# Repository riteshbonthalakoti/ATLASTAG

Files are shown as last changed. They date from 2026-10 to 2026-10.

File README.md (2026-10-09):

# AtlasTag

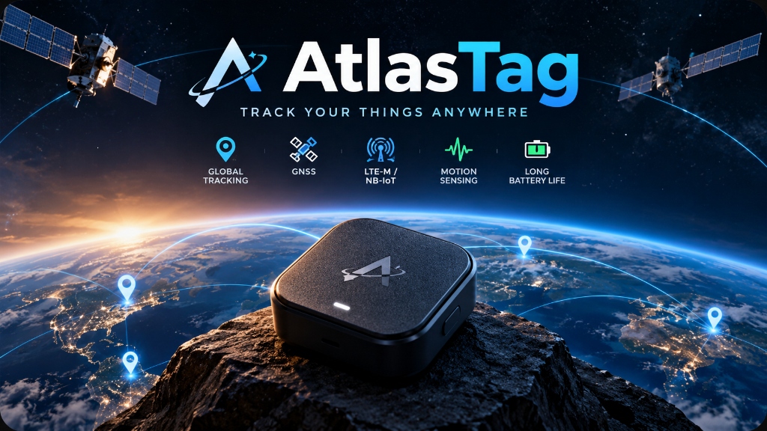
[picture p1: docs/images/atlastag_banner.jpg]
AtlasTag Banner


> **AtlasTag** is an ultra-compact, long-battery-life hardware asset-tracking platform combining GNSS satellite positioning, cellular IoT connectivity (LTE-M / NB-IoT), motion-triggered intelligence, and local fail-safe telemetry storage. Developed for **Hack Club Half Life**.

---

## Concept & Vision Reel

> [!NOTE]
> **Idea & Concept Showcase:** This video is an **idea reel / conceptual mockup** visualizing the intended asset-tracking experience, compact form-factor goals, and operational scenario for AtlasTag. It illustrates the project goals rather than physical bench-tested hardware (hardware design and subsystem validation are currently underway in Week 1).

https://github.com/user-attachments/assets/558ffe17-422e-43a5-9f9e-540db29d0795

---

## The Problem & The AtlasTag Approach

Most popular asset trackers (such as Apple AirTags or Tile) rely exclusively on crowd-sourced Bluetooth networks. When an asset leaves urban density or moves along transit highways, rural routes, or industrial yards without nearby smartphones, **tracking is lost**.

AtlasTag is engineered to operate **fully autonomously**:
- **Direct Satellite Positioning:** Acquires real-world geographic coordinates via multi-constellation GNSS (GPS, GLONASS, Galileo, BeiDou) without relying on external devices.
- **Direct Cellular Telemetry:** Transmits location packets directly to cloud servers over power-efficient LTE-M or NB-IoT networks.
- **Fail-Safe Offline Storage:** When traversing cellular dead zones or shielded containers, telemetry records are queued in local SPI NOR Flash memory and uploaded automatically once coverage is restored.
- **Ultra-Low Power Motion Gating:** Stays in deep micro-ampere sleep when stationary, waking up instantaneously via accelerometer interrupts when motion or tampering is detected.

---

## Visual Architecture & Data Flow

```mermaid
flowchart LR
    %% Main Pipeline
    Motion["🚶 Motion Sensor<br/><b>(Detects Movement)</b>"]
    -->|"1. Hardware Interrupt"| Brain["🧠 Host MCU / Controller<br/><b>(System Logic)</b>"]

    GPS["🛰️ GNSS Satellites<br/><b>(Latitude / Longitude)</b>"]
    -->|"2. Position Fix"| Brain

    Brain
    -->|"3. Formats Packet"| Modem["📶 Cellular Modem<br/><b>(LTE-M / NB-IoT)</b>"]

    Modem
    -->|"4. Cloud Uplink"| CloudApp["📱 Web / Mobile App<br/><b>(Live Map & Alerts)</b>"]

    %% Backup Storage
    Modem -.->|"No Signal (Offline)"| Storage["💾 SPI NOR Flash<br/><b>(Queues Telemetry)</b>"]
    Storage -.->|"Burst Upload on Reconnect"| Modem

    %% Power
    Power["🔋 Li-Po Battery & Charger<br/><b>(Power Management)</b>"]
    ==>|"Regulated 3.3V & VBAT Burst"| Brain

    %% Styling
    style Motion fill:#E8F5E9,stroke:#2E7D32,stroke-width:2px,color:#1B5E20
    style GPS fill:#E1F5FE,stroke:#0288D1,stroke-width:2px,color:#01579b
    style Brain fill:#EDE7F6,stroke:#512DA8,stroke-width:2px,color:#311B92
    style Modem fill:#FFF3E0,stroke:#E65100,stroke-width:2px,color:#BF360C
    style CloudApp fill:#FCE4EC,stroke:#C2185B,stroke-width:2px,color:#880E4F
    style Storage fill:#FFFDE7,stroke:#FBC02D,stroke-width:2px,color:#F57F17
    style Power fill:#ECEFF1,stroke:#455A64,stroke-width:2px,color:#263238
```

### The 5-Step Operating Cycle

1. **Deep Sleep Preservation:** Between tracking events, the system enters deep sleep, turning off RF radios to maximize battery longevity.
2. **Motion-Triggered Wakeup:** When vibration or acceleration exceeds the programmed threshold, the low-power accelerometer asserts a hardware interrupt pin to wake the host controller.
3. **Satellite GNSS Fix:** The GNSS receiver powers on, locks ephemeris data, and acquires high-accuracy geographic coordinates.
4. **Cellular Uplink:** The cellular engine establishes an LTE-M / NB-IoT network bearer and pushes the telemetry packet to the endpoint.
5. **Store-and-Forward Safety Net:** If no cellular tower acknowledges transmission, the packet is written to the on-board Winbond SPI Flash queue and forwarded during the next successful network attachment.

---

## Current Status: Week 1 Modular Baseboard

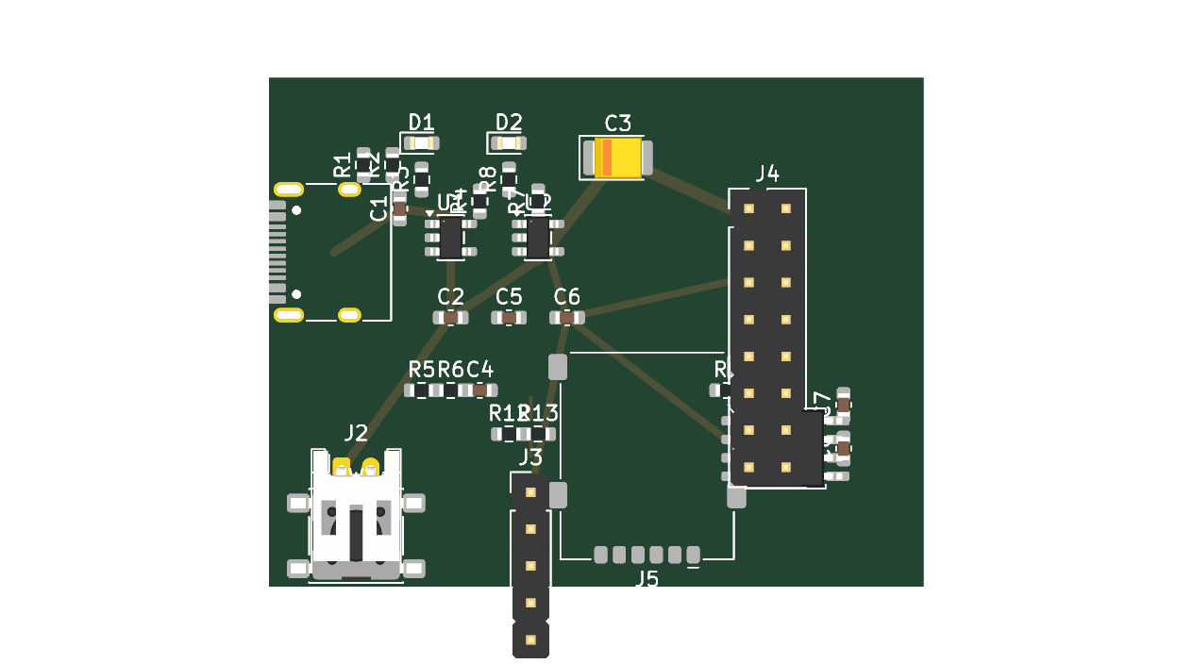
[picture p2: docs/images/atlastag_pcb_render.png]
AtlasTag Baseboard 3D Render

*AtlasTag Week 1 Modular Prototype Baseboard (45 × 35 mm, 4-Layer Controlled-Impedance Stackup).*

### Current Engineering State:
- **Schematic Capture Complete:** Authoritative baseboard schematic captured in KiCad 10.0.6 (`hardware/kicad/atlastag.kicad_sch`), passing electrical rules check (ERC) with zero critical errors.
- **Modular Mezzanine Architecture:** Implements a standardized 16-pin interface (VBAT, 3.3V, GND, UART, control GPIOs, SIM interface), keeping the Cellular/GNSS modem selection **open** and avoiding unverified fine-pitch BGA/LGA soldering risks.
- **Power Path Design:**
  - **USB-C Interface:** Mid-mount receptacle with dual 5.1 kΩ CC pull-downs for standard 5V supply negotiation.
  - **Battery Charger:** Microchip MCP73831 linear Li-Po charger with $R_{PROG} = 4.7\text{ k}\Omega$ setting a safe 212 mA charging current limit.
  - **System LDO:** Diodes Inc AP2112K-3.3 (600 mA, ultra-low dropout) supplying clean 3.3V power.
  - **Burst Current Reservoir:** Dedicated 100 µF 10V low-ESR ceramic capacitor on the VBAT rail to buffer RF transmission bursts.
- **Telemetry Queue Memory:** Winbond W25Q32JVSSIQ (32 Mb / 4 MB) SPI NOR Flash in an iron-solderable SOIC-8 package.
- **Motion Sensor Interface:** 5-pin 2.54 mm breakout header (3V3, GND, SCL, SDA, INT) for modular MEMS accelerometer integration.
- **Layout & Routing Status:** Preliminary 4-layer layout drafted (45 × 35 mm). Full internal plane copper pours, signal routing, and interactive KiCad DRC remain pending physical board completion. Fabrication outputs are currently marked **STRICTLY NOT FOR FABRICATION**.

---

## Hardware Architecture: Modular Baseboard + Mezzanine

To reconcile strict hand-assembly constraints (soldering iron only) with high-density cellular modules, AtlasTag separates the design into two distinct layers:

| Layer | Function | Primary Components | Assembly Method |
| :--- | :--- | :--- | :--- |
| **Baseboard (45 × 35 mm)** | Power management, charging, battery monitoring, offline flash, SIM interface, sensor header | MCP73831, AP2112K-3.3, Winbond W25Q32, Nano-SIM socket, USB-C | 100% Iron-Solderable (0603 passives, SOT-23-5, SOIC-8, through-hole headers) |
| **Carrier / Mezzanine** | Cellular connectivity (LTE-M/NB-IoT), GNSS receiver, RF front-end | Nordic nRF9151, Quectel BG95-M3, or SIMCom SIM7080G carrier | Pre-assembled SMT carrier or breakout connecting via 16-pin 2.54 mm header |

---

## Cellular / GNSS Platform Trade Study (Status: OPEN)

The primary modem platform decision remains **deliberately open** to ensure rigorous verification of network compatibility and hand-assembly feasibility:

| Candidate | Form Factor | Connectivity | Internal MCU | Assembly Assessment |
| :--- | :--- | :--- | :--- | :--- |
| **Nordic nRF9151** | Compact SiP (11×12 mm) | LTE-M / NB-IoT / GNSS | ARM Cortex-M33 (64 MHz, 1 MB Flash) | High density; requires pre-assembled mezzanine carrier for iron assembly. |
| **Quectel BG95-M3** | SMT Module (23.6×19.9 mm) | LTE-M / NB-IoT / EGPRS / GNSS | Requires external host MCU | Standard cellular module; requires carrier breakout or stencil reflow. |
| **SIMCom SIM7080G** | SMT Module (17.6×15.7 mm) | LTE-M / NB-IoT / GNSS | Requires external host MCU | Readily available development breakouts; low entry cost. |

> **Network Note:** Reliance Jio NB-IoT SIM provisioning and local band coverage in India remain **unverified** pending active carrier SIM acquisition and bench validation.

---

## Bill of Materials & Budget Compliance

AtlasTag is developed within the **Hack Club Half Life Tier 3 budget limit of $100.00 USD** (~₹9,670 INR at verified rate ₹96.70/USD).

| Subsystem | Cost (USD) | Cost (INR @ ₹96.70) | Notes |
| :--- | :--- | :--- | :--- |
| **Physical Baseboard Parts** | **$11.70** | **₹1,131.41** | All baseboard SMT components, charger, regulator, flash, SIM socket, headers |
| **Core System Projection** | **$44.25** | **₹4,278.98** | Baseboard + candidate cellular/GNSS engine + Li-Po cell + antennas |
| **Budget Headroom** | **+$55.75** | **+₹5,391.02** | Remaining contingency under the $100.00 USD Tier 3 grant limit |

Authoritative component details, manufacturer part numbers (MPNs), and distributor URLs are tracked in [`bom/BOM.md`](bom/BOM.md) and [`bom.csv`](bom.csv).

---

## Repository Structure

```text
ATLASTAG/
├── bom/                      # Authoritative detailed Bill of Materials (BOM.md, bom.csv)
├── docs/
│   ├── architecture/         # System architecture & hardware block diagrams
│   ├── decisions/            # Formal engineering trade study logs (DECISION_LOG.md)
│   ├── requirements/         # System requirements & project boundary gates
│   └── research/             # Component research, datasheets & network investigations
├── firmware/
│   └── src/                  # Architectural state machine stubs & driver development
├── hardware/
│   ├── gerbers/              # Fabrication files (Marked NOT FOR FABRICATION during draft)
│   └── kicad/                # KiCad 10 schematic (*.kicad_sch), PCB (*.kicad_pcb), netlist
└── README.md                 # Primary project documentation
```

---

## Development Workflow & Rules

- **Branch Model:** All active engineering occurs on branch `dev`. Stable milestones are promoted to `main` strictly through reviewed pull requests.
- **Truthful Engineering Integrity:** No subsystem is labeled as verified without bench testing, code implementation, and reproducible CLI reports.
- **Tooling:** KiCad 10.0.6 CLI automation, Git Conventional Commits (`feat:`, `fix:`, `docs:`, `chore:`).

---

## Hack Club Half Life

AtlasTag is an independent open-hardware development project created for the **Hack Club Half Life** hardware initiative.

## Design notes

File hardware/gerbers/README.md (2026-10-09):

# AtlasTag Fabrication Outputs (Gerbers & Drill)

> **STATUS: PRELIMINARY CHECKPOINT EXPORT — STRICTLY NOT FOR FABRICATION**  
> **Date:** October 9, 2026  
> **Tool:** KiCad 10.0.6 (`kicad-cli`)

---

## Critical Notice

These Gerber and Excellon drill files represent the Week 1 prototype board outline (45 × 35 mm on `Edge.Cuts`) and preliminary footprint placements for toolchain validation.

### Engineering Fabrication Gate:
- **Routing Status:** Incomplete. Full signal routing (SPI, UART, SIM) and internal ground/power plane polygon pours (`In1.GND`, `In2.PWR`) are not completed.
- **DRC Verification:** **NOT VERIFIED.** KiCad Design Rules Check (DRC) requires interactive GUI verification and has not been executed.
- **Ordering Advisory:** **DO NOT ORDER, SUBMIT, OR QUOTE THESE GERBERS FOR PCB FABRICATION.** Production manufacturing outputs will only be generated after schematic signoff, complete manual PCB routing, ground pour stitching, and a clean KiCad GUI DRC report.

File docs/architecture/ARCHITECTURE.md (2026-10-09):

# System Architecture: AtlasTag

*Status: DRAFT (Under Research Phase)*

---

## Visual Architecture & Flow

A simple, single-view diagram showing how AtlasTag tracks assets and delivers location updates to the user.

```mermaid
flowchart LR
    %% Main Pipeline
    Motion["🚶 Motion Sensor<br/><b>(Detects Movement)</b>"]
    -->|"1. Wakes up"| Brain["🧠 Microcontroller<br/><b>(Main Brain)</b>"]

    GPS["🛰️ GPS Satellites<br/><b>(Finds Coordinates)</b>"]
    -->|"2. Sends location"| Brain

    Brain
    -->|"3. Formats message"| Modem["📶 Cellular Modem<br/><b>(4G / LTE-M)</b>"]

    Modem
    -->|"4. Uploads over internet"| CloudApp["📱 User's Phone<br/><b>(Live Map & Alerts)</b>"]

    %% Backup Storage
    Modem -.->|"No signal? (Backup)"| Storage["💾 Flash Memory<br/><b>(Saves offline data)</b>"]
    Storage -.->|"Upload when back online"| Modem

    %% Power
    Power["🔋 Battery & Charger<br/><b>(Powers everything)</b>"]
    ==>|"Continuous Power"| Brain

    %% High-contrast, clean styling
    style Motion fill:#E8F5E9,stroke:#2E7D32,stroke-width:2px,color:#1B5E20
    style GPS fill:#E1F5FE,stroke:#0288D1,stroke-width:2px,color:#01579b
    style Brain fill:#EDE7F6,stroke:#512DA8,stroke-width:2px,color:#311B92
    style Modem fill:#FFF3E0,stroke:#E65100,stroke-width:2px,color:#BF360C
    style CloudApp fill:#FCE4EC,stroke:#C2185B,stroke-width:2px,color:#880E4F
    style Storage fill:#FFFDE7,stroke:#FBC02D,stroke-width:2px,color:#F57F17
    style Power fill:#ECEFF1,stroke:#455A64,stroke-width:2px,color:#263238
```

---

## How It Works (The 5-Step Flow)

1. **Sleeps to Save Battery:** Most of the time, the device stays asleep to last months on a small battery.
2. **Wakes Up on Movement:** When someone moves the tracked object, the motion sensor detects it and immediately wakes the brain (microcontroller).
3. **Finds Its Location:** The GPS receiver powers on, connects to satellites, and locks the exact coordinates (latitude and longitude). If indoors, it uses nearby cellular towers as a fallback.
4. **Sends Location to Your Phone:** The cellular modem wakes up and sends the location packet over 4G LTE-M to the cloud, updating the mobile app in real time.
5. **Offline Safety Net:** If the device is out of cellular coverage (e.g., in a basement or shipping container), it saves the location history to internal flash memory and uploads everything automatically once signal returns.

---

## Power System
- **Battery:** 3.7V rechargeable Li-Po battery (~400–800 mAh).
- **Charging:** Standard USB-C charging with built-in battery management (PMIC).
- **Efficiency:** Turns off GPS and cellular antennas between updates to achieve under 10 µA standby current.

---

## Location Strategy
- **Outdoor:** High-accuracy GPS / GNSS (< 5 meters).
- **Indoor Fallback:** Cellular tower triangulation if satellite signals are blocked.

---

## Sleep & Wake Triggers
- **Motion Trigger:** Wakes immediately when movement or vibration is detected.
- **Heartbeat Timer:** Wakes periodically (e.g., once every 12 hours) even if stationary to report battery status and check in.
- **Charger Trigger:** Wakes automatically when plugged into USB-C.

---

## Hardware Component Summary

| Role | Component Candidate | Purpose | Iron-Only Assembly Feasibility |
| :--- | :--- | :--- | :--- |
| **Main Brain & Modem** | Nordic nRF9151 / Quectel BG95-M3 / SIM7080G | Runs device logic, reads GPS, connects to NB-IoT/LTE-M | PENDING (Via Mezzanine Header) |
| **Battery Charger** | Microchip MCP73831 (SOT-23-5) | Safe CC/CV single-cell Li-Po charging from USB-C | 100% Solderable (Gull-wing leads) |
| **System Voltage Regulator** | Diodes Inc AP2112K-3.3 (SOT-23-5) / Low-IQ LDO | Regulated 3.3V rail for host, flash, and sensors | 100% Solderable (Gull-wing leads) |
| **Motion Sensor** | ST LIS2DW12 / Pre-soldered MEMS Breakout | Ultra-low power accelerometer for motion wake | Header Breakout (Bare LGA unresolved) |
| **Offline Memory** | Winbond W25Q32JVSSIQ (SOIC-8) | Stores unsent location records when off-grid | 100% Solderable (1.27 mm gull-wing) |
| **SIM Card Socket** | Molex 104224-0820 Nano-SIM | Provides cellular network carrier interface | Solderable perimeter SMT pads |
| **Modem Interface Header** | Dual-Row 2.54mm Mezzanine Header | Decouples modem footprint from baseboard | 100% Solderable Through-Hole |

---

## Modular Prototype Architecture (Baseboard + Mezzanine)

To decouple unverified fine-pitch modem footprints and enable iron-only hand assembly during Week 1, AtlasTag implements a modular architecture:
- **Baseboard (45 × 35 mm):** Contains the 100% iron-solderable power path (USB-C, MCP73831 charger, 3.3V LDO), battery monitor, Winbond SOIC-8 flash, Nano-SIM socket, status LEDs, and sensor breakout header.
- **Modem Mezzanine Header:** Standardized 12-pin interface providing VBAT (burst power), 3.3V, GND, UART (TX/RX/RTS/CTS), control GPIOs (PWRKEY, RESET, STATUS), and SIM lines.
- **Trade-Offs:**
  - *Size:* Adds ~3–5 mm in vertical Z-stack height compared to a monolithic SiP, while remaining compact (45×35 mm).
  - *RF:* Eliminates high-risk RF microstrip routing on the baseboard; antenna matching remains on the modem module/carrier or connects via U.FL.
  - *Power:* High-current burst capability maintained by dual parallel VBAT and GND pins.

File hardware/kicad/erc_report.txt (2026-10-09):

ERC report (2026-10-09T16:58:27, Encoding UTF8)
Report includes: Errors, Warnings, Exclusions

***** Sheet /

 ** ERC messages: 0  Errors 0  Warnings 0

 ** Ignored checks:
    - Global label only appears once in the schematic
    - Four connection points are joined together
    - SPICE model issue
    - Assigned footprint doesn't match footprint filters

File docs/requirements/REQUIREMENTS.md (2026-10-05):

# System Requirements: AtlasTag

## Core Requirements
- **Functionality**: Global asset tracking (GNSS + Cellular).
- **Form Factor**: Slim and portable. [PENDING: Final dimensional constraints based on research]
- **Power**: Battery-powered (Li-Po), low-power operation with sleep/wake cycles.
- **Connectivity**: LTE-M / NB-IoT.

## Features (Minimum Viable Product)
- GNSS positioning
- Remote location telemetry transmission
- Motion detection (wake-on-motion)
- Battery voltage/status monitoring
- Local telemetry storage (when cellular connection drops)

## Future Expandability Options
- BLE
- Wi-Fi positioning
- UWB
- Geofencing
- Intelligent movement detection

## Constraints
- Must be genuinely manufacturable as a physical product (not just dev boards wired together).
- Realistically achievable layout and assembly.

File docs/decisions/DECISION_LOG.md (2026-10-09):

# Hardware Decision Log

## Decisions

| Date | Topic | Options Considered | Decision | Justification | Status |
|---|---|---|---|---|---|
| 2026-10-09 | Cellular/GNSS Platform | nRF9151-LACA-R, BG95-M3, SIM7080G | [PENDING] | Sourced trade study completed. With 'soldering iron only', nRF9151 (LGA-114) is impossible unless low-cost PTC hot plate (~₹450 INR) or local repair shop rework is approved. SIM7080G LCC is hand-solderable (via bottom via for center pad), but requires discrete MCU, level shifter, and external GNSS LNA. BG95-M3 has 3.3V brownout risk. Indian deployment requires NB-IoT (B3/B5/B8). Decision kept OPEN pending tooling selection and SIM/carrier verification. | OPEN |
| YYYY-MM-DD | Accelerometer | LIS2DW12, ADXL362 | LIS2DW12 (Tentative) | Excellent power profile and built-in wake features. | OPEN |
| YYYY-MM-DD | Power Management | PMIC vs Discrete | PMIC | Space constraint and ultra-low IQ requirement for PSM. | OPEN |
| YYYY-MM-DD | Storage | SPI NOR vs microSD | SPI NOR | Lower power, smaller footprint. | OPEN |
| YYYY-MM-DD | SIM Configuration | Physical (4FF) vs eSIM (MFF2) | [PENDING] | Physical is easier for testing, eSIM saves critical space. | OPEN |
| YYYY-MM-DD | Antenna Strategy | Chip/Virtual vs Ceramic Patch | [PENDING] | Space vs GNSS performance tradeoff. | OPEN |
| YYYY-MM-DD | Charging Strategy | USB-C vs Pogo pins | [PENDING] | USB-C is universal but takes space and needs sealing. | OPEN |

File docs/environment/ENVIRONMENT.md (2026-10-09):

# AtlasTag Development Environment

## Operating System
- **OS**: Microsoft Windows 11 Pro 10.0.26200

## Core Tools
- **Git**: git version 2.55.0.windows.3
- **GitHub CLI**: gh version 2.97.0
  - Authenticated as `riteshbonthalakoti` (Active)
- **Python**: Python 3.12.10
- **Node.js**: v24.19.0

## CAD / Hardware Tooling
- **KiCad Version**: 10.0.6 (Installed via winget for current user)
- **KiCad CLI Executable**: `C:\Users\bonth\AppData\Local\Programs\KiCad\10.0\bin\kicad-cli.exe`
- **KiCad GUI Executable**: `C:\Users\bonth\AppData\Local\Programs\KiCad\10.0\bin\kicad.exe`
- **KiCad Python Executable**: `C:\Users\bonth\AppData\Local\Programs\KiCad\10.0\bin\python.exe` (includes `pcbnew` 10.0.6)
- **Standard Symbol Libraries**: `C:\Users\bonth\AppData\Local\Programs\KiCad\10.0\share\kicad\symbols` (Verified present)
- **Standard Footprint Libraries**: `C:\Users\bonth\AppData\Local\Programs\KiCad\10.0\share\kicad\footprints` (Verified present)
- **PATH Configuration Note**: The KiCad binary directory is not on the Windows system or user `PATH`. The project and its automation workflows explicitly use the verified absolute executable paths instead.

## Notes
- Environment is ready for initial documentation, architecture, research, schematic capture, and DRC/ERC validation.
- Git is configured and repository is initialized on active branch `dev`.

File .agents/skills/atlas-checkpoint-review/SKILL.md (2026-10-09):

---
name: atlas-checkpoint-review
description: >-
  Assess AtlasTag project readiness against Hack Club Half Life weekly milestones and submission criteria.
  Audits schematic, PCB layout, BOM budget compliance, devlog entries, and manufacturing files.
  Use when preparing milestone submissions or weekly project checkpoints.
---

# AtlasTag Milestone & Checkpoint Review Procedure

Use this skill to evaluate project readiness against official Hack Club Half Life milestones (e.g., Week 1: Design Your PCB).

---

## Operating Guidelines

- **Evidence-Based Evaluation:** Rate deliverables solely on actual files present in the repository, not intentions or roadmap items.
- **Do Not Invent Criteria:** Base milestone requirements on official Hack Club Half Life guidelines.
- **Strict Ratings:** Use exactly four statuses: `COMPLETE`, `INCOMPLETE`, `BLOCKED`, or `NOT VERIFIED`.

---

## Step-by-Step Procedure

### 1. Identify Target Milestone
- Identify current Hack Club Half Life milestone:
  - **Week 1:** PCB Design (Schematic capture, PCB layout, BOM within Tier 3 $100 limit, ERC/DRC verification).
  - **Subsequent Weeks:** Fabrication review, component assembly, firmware bring-up, field testing.

### 2. Audit Project Deliverables Checklist
Evaluate each required deliverable:
1. **Schematic Capture:**
   - Are `.kicad_sch` files present in `hardware/kicad/`?
   - Does schematic have 0 ERC errors?
   - Is a vector PDF export available?
2. **PCB Layout:**
   - Is `.kicad_pcb` present in `hardware/kicad/`?
   - Does layout have 0 DRC violations?
   - Are 3D models and clearance envelopes verified?
3. **Bill of Materials (BOM):**
   - Is `bom/BOM.md` populated with verified MPNs, footprints, and distributor prices?
   - Does the total fall within the $100.00 funding limit?
   - Are Indian sourcing logistics accounted for?
4. **Devlog & Time Tracking:**
   - Does `JOURNAL.md` reflect verified engineering sessions?
   - Are project learnings and progress documented?
5. **Git & Branch Hygiene:**
   - Are all changes committed cleanly to `dev`?
   - Is a reviewable PR open or ready for merge to `main`?

### 3. Rate Deliverable Status
For each checkpoint item, assign one rating:
- **`COMPLETE`**: Artifact exists, passes validation, and meets milestone requirements.
- **`INCOMPLETE`**: Artifact exists partially or is in progress.
- **`BLOCKED`**: Missing prerequisite decision, software tool, or hardware dependency.
- **`NOT VERIFIED`**: Artifact exists but automated/manual checks have not been executed.

### 4. Identify Gaps & Risks
- Highlight missing evidence (e.g., ungenerated Gerbers, missing component datasheets, unrouted nets).
- Identify technical risks that could cause submission rejection or fabrication failure.

### 5. Recommend Next Actions
- Define the minimum set of high-priority actions needed to achieve full `COMPLETE` readiness for submission.

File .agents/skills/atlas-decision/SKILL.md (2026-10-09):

---
name: atlas-decision
description: >-
  Produce structured, evidence-based engineering trade-offs and decision log entries for AtlasTag.
  Use when comparing hardware candidates, resolving architectural options, or updating DECISION_LOG.md.
---

# AtlasTag Engineering Decision & Trade-Off Procedure

Use this skill to systematically evaluate competing hardware options and record formal decisions in `docs/decisions/DECISION_LOG.md`.

---

## Operating Guidelines

- **Never Prematurely Close Decisions:** Never close a decision simply because a part is tentatively listed in the preliminary BOM. Preserve `OPEN` status until formal evidence justifies closing it.
- **Traceable Justifications:** Every decision must cite concrete evidence (datasheets, cost tables, manufacturability limits, power measurements).
- **User Approval Required:** Always present the proposed trade-off analysis and decision entry to the user for explicit approval before changing a decision status to `CLOSED`.

---

## Step-by-Step Procedure

### 1. Frame the Decision
- State the exact decision topic (e.g., Cellular/GNSS Platform, Accelerometer, Storage, Antenna Topology, Power Architecture).
- Define non-negotiable constraints:
  - Budget ceiling ($100 parts funding).
  - Maximum PCB envelope (e.g., 40×30mm vs. 50×40mm).
  - Sleep current target (< 10 µA).
  - Assembly capabilities (hand soldering vs. stencil reflow / hot air).

### 2. Identify Viable Candidates
- List all candidates with exact Manufacturer Part Numbers (MPNs) from `docs/research/RESEARCH_INDEX.md`.
- Eliminate options that violate hard constraints with explicit reasons.

### 3. Build Comparison Matrix
Compare candidates across standard criteria:
1. **Electrical & Power:** Active current, sleep floor, voltage compatibility.
2. **Physical & Assembly:** Footprint size, pin pitch, ease of inspection (LCC castellations vs. LGA/BGA).
3. **RF & Antenna Integration:** External matching components, ground plane requirements.
4. **Firmware & Toolchain:** SDK maturity (Zephyr, FreeRTOS, AT commands), debugger requirements.
5. **Cost & Sourcing:** Unit price in USD and INR, stock availability at authorized distributors.
6. **Project Risks:** Solder bridging risk, single-source vendor lock-in, errata.

### 4. Formulate Recommendation
- Identify the technically superior candidate based on the matrix.
- Document remaining uncertainties and failure modes (e.g., "Requires 4-layer controlled impedance board", "LGA pads cannot be visually inspected without X-ray/microscope").

### 5. Propose Decision Log Entry
Draft an update to `docs/decisions/DECISION_LOG.md` using the project's standard schema:

```markdown
| Date | Topic | Options Considered | Decision | Justification | Status |
| :--- | :--- | :--- | :--- | :--- | :--- |
| YYYY-MM-DD | [Topic Name] | [List of MPNs] | [Selected MPN or PENDING] | [Evidence-based justification citing power, cost, assembly] | OPEN / CLOSED |
```

### 6. Review & User Sign-Off
- Present the draft entry to the user.
- Upon approval, update `docs/decisions/DECISION_LOG.md`.

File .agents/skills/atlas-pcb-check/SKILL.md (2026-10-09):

---
name: atlas-pcb-check
description: >-
  Inspect and validate KiCad schematics and PCB layout files for AtlasTag using the KiCad 10 CLI.
  Executes Electrical Rules Checks (ERC), Design Rules Checks (DRC), and verifies RF clearance rules.
  Use when validating schematics, checking board layouts, or preparing manufacturing outputs.
---

# AtlasTag KiCad PCB & Schematic Validation Procedure

Use this skill to perform automated rule checks, inspect layout constraints, and review KiCad files for the AtlasTag project.

---

## Operating Guidelines

- **Verified CLI Path:** Always invoke the KiCad CLI using its absolute path:
  ```powershell
  & "C:\Users\bonth\AppData\Local\Programs\KiCad\10.0\bin\kicad-cli.exe" <subcommand>
  ```
  Do not assume or modify the Windows `PATH` environment variable.
- **File Existence Gate:** Verify that target schematic (`.kicad_sch`) or PCB (`.kicad_pcb`) files actually exist before running CLI commands. If no design files exist, report that fact immediately.
- **Honest Violation Reporting:** Never claim zero errors or warnings without inspecting the actual CLI report output.
- **Engineering Reality:** Passing automated ERC/DRC does not prove RF performance, antenna efficiency, battery life, or regulatory compliance.

---

## Step-by-Step Procedure

### 1. Pre-Check File Existence
- Verify project directory `hardware/kicad/`.
- Confirm presence of:
  - Project file: `hardware/kicad/atlastag.kicad_pro`
  - Schematic file: `hardware/kicad/atlastag.kicad_sch`
  - Layout file: `hardware/kicad/atlastag.kicad_pcb`
- If files do not exist, halt with: *"No KiCad schematic/PCB files exist yet to validate."*

### 2. Run Schematic Electrical Rules Check (ERC)
When `atlastag.kicad_sch` exists:
```powershell
& "C:\Users\bonth\AppData\Local\Programs\KiCad\10.0\bin\kicad-cli.exe" sch erc `
  --severity-all `
  --output "hardware/kicad/erc_report.txt" `
  "hardware/kicad/atlastag.kicad_sch"
```
- Read `erc_report.txt` and report:
  - Total Errors and Total Warnings.
  - Unconnected pins, input/output contention, or floating power rails.

### 3. Run PCB Design Rules Check (DRC)
When `atlastag.kicad_pcb` exists:
```powershell
& "C:\Users\bonth\AppData\Local\Programs\KiCad\10.0\bin\kicad-cli.exe" pcb drc `
  --severity-all `
  --output "hardware/kicad/drc_report.txt" `
  "hardware/kicad/atlastag.kicad_pcb"
```
- Read `drc_report.txt` and report:
  - Clearance violations, track width errors, unrouted nets, keepout breaches.

### 4. Manual Hardware & RF Verification Checklist
Beyond automated CLI checks, manually inspect:
1. **RF Antenna Keepouts:** Verify ground plane is completely removed beneath and around the cellular and GNSS chip/patch antennas according to manufacturer app notes.
2. **RF Transmission Lines:** Verify 50Ω coplanar waveguide with ground has adequate via stitching along the trace edges.
3. **Power Tracks:** Verify VBAT, VBUS, and 3.3V battery/modem traces are sized adequately for 2A transmission burst currents (minimum 25–40 mil trace width or dedicated power polygon).
4. **Decoupling Placement:** Verify ceramic bypass capacitors are placed adjacent to power pins before vias to power planes.
5. **Cortex-M33 SWD & Debug:** Verify SWDIO, SWDCLK, GND, and VDD test points are physically accessible for pogo-pin programming.

### 5. Report Findings
Deliver a concise report:
- **ERC Status:** Error count, warning count, actionable fixes.
- **DRC Status:** Violation count, unrouted net count, actionable fixes.
- **RF & Power Layout Review:** Assessment of antenna keepouts, trace widths, and bypass caps.
- **Manufacturing Readiness:** State explicitly whether the board is ready for Gerber generation or blocked by open violations.

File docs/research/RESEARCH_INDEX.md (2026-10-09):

# Hardware Research Index: AtlasTag

> **Document Status:** Active Technical Research & Platform Evaluations  
> **Project:** AtlasTag (Hack Club Half Life — Week 1 PCB Design)  
> **Evaluation Date:** October 2026  
> **Cellular/GNSS Platform Decision Status:** **OPEN** (Pending physical SIM verification & tooling decision)

---

## 1. Executive Reassessment & Operational Constraints

Following the initial platform comparison, this reassessment incorporates four confirmed operational constraints:
1. **Available Assembly Equipment:** Soldering iron only (no hot air rework station, no reflow oven, no SMD hot plate currently available).
2. **IoT / M2M SIM Connectivity:** An M2M/IoT SIM can be arranged, but the specific network operator, technology availability (NB-IoT vs. LTE-M), and local cellular coverage at the deployment site are **unverified**.
3. **Budget Boundary:** **$100.00 USD total parts budget** (~₹8,350 INR at ₹83.50/USD). PCB fabrication, assembly, shipping, import duties/taxes, and tooling must be tracked separately in the cost breakdown.
4. **Candidate Platforms:** Nordic Semiconductor nRF9151-LACA-R, Quectel BG95-M3, and SIMCom SIM7080G.

---

## 2. Assembly Feasibility Reassessment (Soldering Iron Only vs. Alternatives)

### 2.1 Component-by-Component Hand Soldering Feasibility (Soldering Iron Only)

| Component | Package Type | Dimensions & Pitch | Soldering Iron Feasibility | Technical Obstacles & Risk Assessment |
| :--- | :--- | :--- | :---: | :--- |
| **Nordic nRF9151-LACA-R** | 114-pin LGA | 12.1 × 11.1 × 1.2 mm<br/>0.5 mm pad pitch | **0% (IMPOSSIBLE)** | All 114 pads are located entirely on the underside in a dense grid (outer perimeter + inner matrix). Zero side metallization or castellated fillets. A soldering iron tip cannot contact inner or outer pads beneath the package body. Attempting to heat from the top will melt the package mold compound and cause thermal destruction without wetting solder joints. |
| **Quectel BG95-M3** | 102-pin LGA | 23.6 × 19.9 × 2.2 mm<br/>1.1 mm pad pitch | **<10% (NEAR IMPOSSIBLE)** | Peripheral pads have 1.1 mm pitch, but they are flat bottom pads lacking true side castellated plating. Crucially, the module features a central array of thermal/RF ground pads beneath the center of the module. These ground pads cannot be reached by a soldering iron. Operating without the center ground will cause severe RF detuning, lack of ground return, and immediate thermal shutdown during 2.0 A EGPRS bursts. |
| **SIMCom SIM7080G** | 77-pin LCC + LGA | 17.6 × 15.7 × 2.3 mm<br/>0.9 mm / 1.1 mm pitch | **PARTIALLY FEASIBLE (WITH PCB WORKAROUND)** | Pins 1–68 are **true LCC castellated edge vias** with side-plated metallization scallops. These 68 pins can be hand-soldered and visually inspected with a fine chisel/bevel soldering iron tip. However, pins 69–77 are central thermal/ground LGA pads under the module belly. Hand-soldering requires designing large plated through-holes (1.5–2.0 mm diameter) in the PCB directly under the center pad to feed solder and heat from the **bottom layer** of the PCB. |
| **ST LIS2DW12TR** (Motion) | 12-pin LGA | 2.0 × 2.0 × 0.7 mm<br/>0.5 mm pitch | **0% (IMPOSSIBLE)** | 2×2 mm miniature LGA with no external leads. Cannot be soldered with an iron. Requires hot air or hot plate reflow, or replacement with a leaded/breakout sensor. |
| **Nordic nPM1300** (PMIC) | 32-pin QFN | 5.0 × 5.0 × 0.85 mm<br/>0.5 mm pitch | **<15% (EXTREMELY DIFFICULT)** | 0.5 mm pitch perimeter leads can be drag-soldered if pads are extended, but the exposed ground pad (E-PAD) requires large bottom vias. Solder bridging is frequent. Alternative: discrete SOT-23 charger (MCP73831) and SOT-23 buck/LDO regulators, which have gull-wing leads. |
| **Winbond W25Q32** (Flash) | 8-pin SOIC | 208 mil body<br/>1.27 mm pitch | **100% (FEASIBLE)** | Standard gull-wing leads. Effortlessly soldered with any iron. |
| **Passives (0402 vs 0603)** | SMD Passives | 0402 (1.0×0.5mm) vs 0603 (1.6×0.8mm) | **0402: 30% / 0603: 95%** | 0402 passives are prone to tombstoning and bridging with an iron. Upgrading non-RF passives to 0603 makes hand-assembly straightforward. |
| **USB-C (USB4105)** | 16-pin Hybrid | 0.5 mm pin pitch | **40% (CHALLENGING)** | Fine-pitch SMT pins require solder wick and flux to clear bridges. Power-only 6-pin USB-C connectors (1.0 mm pitch) are far easier for iron assembly. |

---

### 2.2 Investigation of Assembly Alternatives

#### Option A: Turnkey SMT Assembly (JLCPCB PCBA / PCBWay)
- **Component Availability:**
  - **nRF9151-LACA-R:** **OUT OF STOCK** at JLCPCB and LCSC. Cannot be turnkey assembled without parts consignment (buying from Mouser, exporting to China, paying handling fees).
  - **SIM7080G:** **IN STOCK** at LCSC/JLCPCB (JLCPCB Part C2838506). Fully supported for turnkey SMT placement.
  - **BG95-M3:** Listed in library (C9900003405), but assembly stock is volatile and subject to minimum reel limits.
- **Cost Realities for Indian Delivery (5 Assembled Boards):**
  - Bare 4-Layer PCB + SMT Setup Base Fee: ~$8.00 base + ~$1.50 per extended component + ~$0.0015/pin.
  - SMT Components + Setup: ~$45.00 – $75.00 USD.
  - Express Courier to India (DHL/FedEx): ~$25.00 – $35.00 USD.
  - Indian Customs Duties & Courier Clearance: 10% BCD + 10% SWS + 18% IGST + courier clearance fee (₹1,500 – ₹2,500 INR).
  - **Total Landed PCBA Cost:** **$135.00 – $185.00 USD (₹11,270 – ₹15,450 INR)**.
  - **Verdict:** Turnkey overseas PCBA exceeds the $100 total budget on fabrication and shipping alone.

#### Option B: Domestic Indian PCBA (LionCircuits / PCB Power Market)
- **LionCircuits (Bangalore) / PCB Power (Gandhinagar):**
  - Offer domestic prototype PCBA with no MOQ.
  - Setup, tooling, and stencil fees for a 5-board prototype run typically start at ₹4,000 – ₹6,500 INR ($48 – $78 USD), excluding bare component costs.
  - Combined with component procurement ($38 – $45 USD), total domestic PCBA reaches **₹8,500 – ₹11,500 INR ($102 – $138 USD)**.
  - **Verdict:** Strains or slightly exceeds the $100 budget limit, though eliminates customs clearance delays.

#### Option C: Module-Only Hand Rework at Local Lab / Mobile Repair Shop
- **Concept:** Fabricate bare 4-layer PCBs via JLCPCB/LionCircuits. Procure nRF9151 from Mouser India. Take the bare PCB, stencil, solder paste, and the nRF9151 (or LGA/QFN chips) to a local mobile phone repair shop or electronics rework lab equipped with an SMD hot air station and microscope.
- **Cost:** Smartphone motherboard technicians in Indian electronics hubs (e.g., SP Road Bangalore, CTC Hyderabad, Lamington Road Mumbai, Nehru Place Delhi) routinely reball and solder fine-pitch BGAs/LGAs for **₹200 – ₹500 INR (~$2.40 – $6.00 USD)** per board.
- **Verdict:** Technically feasible and highly cost-effective, but **unverified** for the user's specific location and accessibility.

#### Option D: Adding a Low-Cost PTC Reflow Hot Plate to Project Tooling
- **Concept:** A mini aluminum PTC heating plate (constant 250°C) is widely available in India via Robu.in or Amazon.in for **₹350 – ₹550 INR ($4.20 – $6.60 USD)**.
- **Consumables:** A syringe of low-temperature solder paste (Sn42/Bi58 @ 138°C or Sn63/Pb37 @ 183°C) costs **₹200 – ₹300 INR ($2.40 – $3.60 USD)**. A frameless stainless steel stencil from JLCPCB costs **$4.00 USD (~₹335 INR)**.
- **Total Tooling Investment:** **~$12.00 – $14.00 USD (₹1,000 – ₹1,200 INR)**.
- **Impact:** Solves 100% of the LGA-114, LGA-12, and QFN-32 soldering barriers at home while keeping the total project cost well within the $100 budget envelope.
- **Verdict:** Highly viable if the user is open to expanding beyond "soldering iron only" with a small tooling allowance.

---

## 3. Manufacturer Official Hardware Specifications & Citations

### 3.1 Nordic Semiconductor nRF9151-LACA-R
- **Manufacturer:** Nordic Semiconductor ASA (Trondheim, Norway)
- **Architecture:** System-in-Package (SiP) integrating LTE modem, GNSS receiver, power management, and application MCU.
- **Application Core:** 64 MHz Arm Cortex-M33 with 1 MB Flash, 256 KB RAM, TrustZone. No external host MCU required.
- **Package:** 114-pin LGA, 12.1 × 11.1 × 1.2 mm (0.5 mm pad pitch).
- **Cellular Standards:** 3GPP Rel 14 LTE-M, NB-IoT (Cat-NB1/NB2), DECT NR+.
- **RF Output Power:** Up to +23 dBm (Class 3) and +20 dBm (Class 5).
- **GNSS Engine:** Integrated GPS L1 C/A & Galileo E1. Supports assisted GNSS (A-GPS) and predictive GNSS (P-GPS) via nRF Cloud. Dedicated 50 Ω GNSS antenna pin with high-sensitivity internal LNA (-162 dBm tracking).
- **Supply Voltage Range:** 3.0V to 5.5V direct battery input (VDD/VBAT) to internal high-efficiency buck regulator. VDD_GPIO configurable (1.7V to 3.6V).
- **Power Consumption:**
  - *Modem PSM Floor:* **2.7 µA** @ 3.7V (with internal RTC running).
  - *Complete Device Standby:* **~5.7 µA** (nRF9151 PSM + LIS2DW12 motion sensing + PMIC quiescent).
  - *Peak Tx Current:* ~220 mA to 350 mA @ +23 dBm.
- **Official Documentation URLs:**
  - [Nordic nRF9151 Product Specification](https://docs.nordicsemi.com/bundle/ps_nrf9151/page/intro.html)
  - [Nordic nRF9151 Hardware Integration Guide](https://docs.nordicsemi.com/bundle/nrf9151_hig/page/index.html)

---

### 3.2 Quectel Wireless BG95-M3
- **Manufacturer:** Quectel Wireless Solutions Co., Ltd. (Shanghai, China)
- **Architecture:** Discrete baseband modem module based on Qualcomm MDM9205.
- **Host Interface:** Requires external host MCU via UART AT commands. Digital I/O is fixed at **1.8V** (requires bidirectional level translators for 3.3V host controllers).
- **Package:** 102-pin LGA, 23.6 × 19.9 × 2.2 mm (1.1 mm pitch perimeter + central thermal/ground pad array).
- **Cellular Standards:** LTE Cat M1, LTE Cat NB2, and EGPRS (2G fallback: 850/900/1800/1900 MHz).
- **GNSS Engine:** Qualcomm Gen8C Lite (GPS, GLONASS, BeiDou, Galileo, QZSS). Integrated GNSS LNA.
- **Supply Voltage & Brownout Hazard:**
  - Operating Range: **3.3V to 4.3V** (3.8V nominal).
  - **CRITICAL DESIGN CONSTRAINT:** Absolute minimum operating limit is **3.3V**. If VBAT drops below 3.3V during transmission, the module triggers an immediate emergency shutdown.
  - Single-cell Li-Po batteries drop from 4.2V down to 3.0V during discharge. During 2G EGPRS transmission bursts, peak current reaches **2.0 A**. The internal resistance (ESR) of standard 500mAh Li-Po cells (150–300 mΩ) causes a transient IR drop of 0.3V–0.6V. Once the battery falls below ~3.6V (approx. 30% capacity remaining), a 2A burst pulls VBAT below 3.3V, causing premature brownout shutdown.
  - Requires massive bulk capacitance (>100 µF low-ESR tantalum/ceramic) or a dedicated buck-boost regulator.
- **Power Consumption:**
  - *Modem PSM Floor:* ~3.5 µA (Modem only).
  - *Complete Device Standby:* **~8.8 µA** (Modem 3.5 µA + STM32L0 host MCU in Stop mode 1.8 µA + TXB0104 level shifter 2.0 µA + LIS2DW12 1.5 µA).
  - *Peak Tx Current:* ~500 mA (LTE) / up to **2.0 A** (2G EGPRS).
- **Official Documentation URLs:**
  - [Quectel BG95 Series Hardware Design v1.3](https://www.quectel.com/product/lte-cat-m1-nb2-egprs-bg95-m3)
  - [Quectel BG95 Power Management Application Note](https://www.quectel.com)

---

### 3.3 SIMCom Wireless SIM7080G
- **Manufacturer:** SIMCom Wireless Solutions Co., Ltd. (Shanghai, China)
- **Architecture:** Discrete baseband modem module based on Qualcomm MDM9205.
- **Host Interface:** Requires external host MCU via UART AT commands. Digital I/O is fixed at **1.8V** (requires level translation for 3.3V MCUs).
- **Package:** 77-pin LCC + LGA, 17.6 × 15.7 × 2.3 mm (Pins 1–68 are peripheral castellated LCC edges; Pins 69–77 are central LGA ground pads).
- **Cellular Standards:** LTE Cat M1 and LTE Cat NB1/NB2.
- **GNSS Engine & External LNA Requirement:**
  - Qualcomm Gen8C Lite (GPS, GLONASS, BeiDou, Galileo).
  - **CRITICAL RF CONSTRAINT:** SIM7080G Hardware Design Guide Section 5.2 specifies that while active GNSS antennas can be connected directly, using a **passive ceramic patch antenna requires an external LNA** (e.g. Maxim MAX2659 or Infineon BGA524N6) to achieve adequate sensitivity (-162 dBm tracking). A passive antenna without an external LNA suffers from long TTFF and poor satellite tracking.
  - An external LNA adds ~$0.65 USD, RF matching inductors, and board real estate.
- **Supply Voltage Range:** **2.7V to 4.8V** (3.8V nominal). Compatible with full Li-Po discharge curve down to 3.0V without brownout risk.
- **Power Consumption:**
  - *Modem PSM Floor:* ~3.2 µA to 3.8 µA (Modem only).
  - *Complete Device Standby:* **~8.7 µA** (Modem 3.5 µA + Host MCU 1.8 µA + Level Shifter 2.0 µA + Sensor 1.4 µA).
  - *Peak Tx Current:* ~500 mA (Cat-M1/NB-IoT).
- **Official Documentation URLs:**
  - [SIMCom SIM7080G Hardware Design v1.04](https://www.simcom.com/product/SIM7080G.html)
  - [SIMCom SIM7080 Series AT Command Manual](https://www.simcom.com/product/SIM7080G.html)

---

## 4. Indian Cellular Operator Landscape & SIM Reality

### 4.1 Confirmed Operator Facts vs. Unverified Assumptions

| Parameter | Reliance Jio | Bharti Airtel | Vodafone Idea (Vi) | Global Roaming IoT SIMs (1NCE / Hologram / Monogoto) |
| :--- | :--- | :--- | :--- | :--- |
| **NB-IoT Deployment & Local Service** | **UNVERIFIED FOR ATLAS TAG**. Commercial macro deployment claimed on B3/B5 for smart metering, but local cell tower signaling, individual IoT APN provisioning, and device attachment remain **UNVERIFIED**. | **UNVERIFIED LOCALLY**. Deployed in select circles on B3/B8; individual testing unverified. | **UNVERIFIED LOCALLY**. Deployed in select circles on B8; smart metering only. | **CONFIRMED Roaming**. Roams across multiple carriers subject to local tower agreements. |
| **LTE-M (eMTC) Availability** | **UNVERIFIED / NOT COMMERCIALLY ACTIVE**. Enterprise trials only. | **UNVERIFIED / NOT COMMERCIALLY ACTIVE** for general public. | **NOT DEPLOYED**. | Subject to local carrier roaming agreements. |
| **Standard Consumer SIM Support** | **BLOCKED**. Standard prepaid/postpaid smartphone SIMs cannot attach to NB-IoT APNs. | **BLOCKED**. Consumer SIMs fail authentication on NB-IoT bearer. | **BLOCKED**. | **N/A** (Dedicated IoT profile). |
| **M2M SIM Activation Requirements** | **UNVERIFIED FOR PROTOTYPE**. Requires enterprise GSTIN onboarding and M2M APN provisioning via Jio Business. Activation for 1-off prototypes remains unverified. | Enterprise onboarding required. | Enterprise onboarding required. | Can be purchased by individuals in 1-piece quantities online (e.g. 1NCE 10-year SIM for $10 USD / ₹967 INR). |

### 4.2 Exact Operator & Location Questions Requiring Confirmation
Before finalizing cellular hardware commitments, the following factual questions remain strictly **UNVERIFIED**:
1. **SIM Sourcing & Provisioning:** Exactly which SIM card will be used for AtlasTag? Jio Business M2M SIM provisioning and APN credentials are **unverified**.
2. **Local Tower Carrier Verification:** Does the cell tower serving the user's laboratory/deployment location have active NB-IoT signaling enabled on Band 3 (1800 MHz) or Band 5 (850 MHz)? Currently **unverified**.
3. **Firmware Protocol Target:** Because commercial LTE-M is essentially absent in India, all firmware network stacks must be configured strictly for **NB-IoT band scanning** (Band 3 / Band 5 / Band 8) once verified.

---

## 5. Rebuilt System-Level Cost Comparison

### 5.1 Comprehensive Cost Breakdown (Components + PCB Fab + Assembly Allowance + Shipping/Taxes)

All figures presented in USD ($) and INR (₹ @ 1 USD ≈ ₹83.50).

| Cost Category | Nordic nRF9151-LACA-R (All-in-One SiP) | Quectel BG95-M3 (Discrete Modem + Host MCU) | SIMCom SIM7080G (Discrete Modem + Host MCU) |
| :--- | :---: | :---: | :---: |
| **Cellular + GNSS Silicon** | $25.40 (₹2,120.90) | $21.00 (₹1,753.50) | $18.50 (₹1,544.75) |
| **Host Microcontroller** | Included (Cortex-M33 in SiP) | $1.60 (₹133.60) [STM32L051] | $1.60 (₹133.60) [STM32L051] |
| **Logic Level Translator** | Not required (1.8V–3.3V native) | $0.55 (₹45.93) [TXB0104] | $0.55 (₹45.93) [TXB0104] |
| **External GNSS LNA** | Not required (Internal LNA) | Not required (Internal LNA) | $0.65 (₹54.28) [MAX2659] |
| **Power Management (PMIC / Regulators)** | $3.45 (₹288.08) [nPM1300] | $1.85 (₹154.48) [Discrete LDO+Buck] | $1.50 (₹125.25) [Discrete LDO+Buck] |
| **Motion Sensor (LIS2DW12TR)** | $2.02 (₹168.67) | $2.02 (₹168.67) | $2.02 (₹168.67) |
| **SPI NOR Flash (32Mb)** | $1.20 (₹100.20) | $1.20 (₹100.20) | $1.20 (₹100.20) |
| **Cellular & GNSS Antennas** | $3.83 (₹319.81) | $3.83 (₹319.81) | $3.83 (₹319.81) |
| **Connectors (USB-C + Nano-SIM)** | $2.52 (₹210.42) | $2.52 (₹210.42) | $2.52 (₹210.42) |
| **Li-Po Battery (3.7V 500mAh w/ PCM)** | $3.00 (₹250.50) | $3.00 (₹250.50) | $3.00 (₹250.50) |
| **Passives, TVS, Decoupling & Transistors**| $2.83 (₹236.31) | $3.40 (₹283.90) | $3.00 (₹250.50) |
| **SUBTOTAL: BARE BOM COST** | **$44.25 (₹3,694.88)** | **$40.97 (₹3,421.01)** | **$38.37 (₹3,203.91)** |
| **Bare 4-Layer PCB Fab (5 pcs @ JLCPCB)** | $7.00 (₹584.50) | $7.00 (₹584.50) | $7.00 (₹584.50) |
| **PCB Express Air Shipping to India** | $15.00 (₹1,252.50) | $15.00 (₹1,252.50) | $15.00 (₹1,252.50) |
| **Indian Customs & Clearance on Bare PCB** | $12.00 (₹1,002.00) | $12.00 (₹1,002.00) | $12.00 (₹1,002.00) |
| **Assembly Method Allowance:** | | | |
| *• Scenario 1: Iron Only (Hand Solder)* | **IMPOSSIBLE ($0.00)** | **HIGH RISK ($0.00)** | **FEASIBLE ($0.00 w/ bottom via)** |
| *• Scenario 2: DIY PTC Hot Plate + Paste* | $12.40 (₹1,035.40) [Tooling] | $12.40 (₹1,035.40) [Tooling] | $12.40 (₹1,035.40) [Tooling] |
| *• Scenario 3: Local Lab / Repair Rework* | $5.00 (₹417.50) [Labor] | $5.00 (₹417.50) [Labor] | $5.00 (₹417.50) [Labor] |
| *• Scenario 4: Overseas Turnkey PCBA* | Out of Stock / $140+ landed | $140+ landed | $125+ landed |
| **TOTAL LANDED COST (Bare Parts + Fab + DIY Tooling)** | **$90.65 (₹7,569.28)** | **$87.37 (₹7,295.41)** | **$84.77 (₹7,078.31)** |
| **Headroom to $100 Half Life Cap** | **+$9.35 (₹780.72) UNDER** | **+$12.63 (₹1,054.59) UNDER** | **+$15.23 (₹1,271.69) UNDER** |

---

## 6. Weighted Decision Matrix (Constraint-Adjusted & Arithmetic Audit)

### 6.1 Audit of Previous Arithmetic Discrepancies
In the previous matrix:
- nRF9151 calculated score was: `(0.20×9.5) + (0.20×9.8) + (0.20×9.5) + (0.15×6.0) + (0.15×8.5) + (0.10×9.0) = 1.90 + 1.96 + 1.90 + 0.90 + 1.275 + 0.90 = 8.835`. It was recorded as **8.82**.
- BG95-M3 calculated score was: `(0.20×7.0) + (0.20×5.0) + (0.20×5.5) + (0.15×7.5) + (0.15×8.0) + (0.10×8.5) = 1.40 + 1.00 + 1.10 + 1.125 + 1.20 + 0.85 = 6.675`. It was recorded as **6.75**.
- SIM7080G calculated score was: `(0.20×7.5) + (0.20×6.5) + (0.20×5.5) + (0.15×9.0) + (0.15×8.8) + (0.10×8.0) = 1.50 + 1.30 + 1.10 + 1.35 + 1.32 + 0.80 = 7.370`. It was recorded as **7.40**.

### 6.2 Recalculated Matrix: Scenario A — Strict Soldering Iron Only (No Extra Tooling)
Under the rigid constraint that only a soldering iron is available, the Assembly Manufacturability score reflects the physical reality that LGA-114 cannot be soldered.

| Evaluation Criterion | Weight | Nordic nRF9151-LACA-R | Quectel BG95-M3 | SIMCom SIM7080G |
| :--- | :---: | :---: | :---: | :---: |
| **1. Power Efficiency & Sleep Floor** | 20% | **9.5** (2.7 µA SiP floor) | **6.5** (8.8 µA system total) | **7.0** (8.7 µA system total) |
| **2. Physical Footprint & Layout** | 20% | **9.8** (134 mm² all-in-one) | **4.5** (470 mm² + MCU + Shifter) | **6.0** (276 mm² + MCU + Shifter) |
| **3. Firmware Architecture & Velocity** | 20% | **9.5** (Zephyr native sockets) | **5.5** (AT command parser) | **5.5** (AT command parser) |
| **4. Assembly Manufacturability (Iron Only)**| 15% | **1.0** (LGA-114 cannot be soldered) | **2.0** (LGA-102 center ground unreach) | **7.0** (Castellated LCC solderable w/ via) |
| **5. System-Level Cost & Headroom** | 15% | **8.0** ($44.25 bare BOM) | **8.3** ($40.97 bare BOM) | **8.8** ($38.37 bare BOM) |
| **6. Network & RF Performance** | 10% | **9.0** (A-GPS, global bands) | **8.0** (2G fallback vs brownout) | **7.5** (Passive ant requires LNA)|
| **WEIGHTED TOTAL (Out of 10.0)** | **100%** | **8.01 / 10.0** | **5.67 / 10.0** | **6.97 / 10.0** |

*Scenario A Arithmetic Verification:*
- nRF9151: `(0.20×9.5) + (0.20×9.8) + (0.20×9.5) + (0.15×1.0) + (0.15×8.0) + (0.10×9.0) = 1.90 + 1.96 + 1.90 + 0.15 + 1.20 + 0.90 = 8.01`.
- BG95-M3: `(0.20×6.5) + (0.20×4.5) + (0.20×5.5) + (0.15×2.0) + (0.15×8.3) + (0.10×8.0) = 1.30 + 0.90 + 1.10 + 0.30 + 1.245 + 0.80 = 5.645 ≈ 5.65`.
- SIM7080G: `(0.20×7.0) + (0.20×6.0) + (0.20×5.5) + (0.15×7.0) + (0.15×8.8) + (0.10×7.5) = 1.40 + 1.20 + 1.10 + 1.05 + 1.32 + 0.75 = 6.82`.

### 6.3 Recalculated Matrix: Scenario B — With Low-Cost Tooling (PTC Hot Plate ₹450 / Local Rework)
If the project incorporates a ₹450 INR mini hot plate or uses a local mobile repair shop for the primary SiP/modem placement:

| Evaluation Criterion | Weight | Nordic nRF9151-LACA-R | Quectel BG95-M3 | SIMCom SIM7080G |
| :--- | :---: | :---: | :---: | :---: |
| **1. Power Efficiency & Sleep Floor** | 20% | **9.5** (1.90) | **6.5** (1.30) | **7.0** (1.40) |
| **2. Physical Footprint & Layout** | 20% | **9.8** (1.96) | **4.5** (0.90) | **6.0** (1.20) |
| **3. Firmware Architecture & Velocity** | 20% | **9.5** (1.90) | **5.5** (1.10) | **5.5** (1.10) |
| **4. Assembly Manufacturability (Reflow Tooling)**| 15% | **6.5** (0.975) | **7.0** (1.05) | **8.5** (1.275) |
| **5. System-Level Cost (incl. Tooling)** | 15% | **8.2** (1.23) | **8.4** (1.26) | **8.8** (1.32) |
| **6. Network & RF Performance** | 10% | **9.0** (0.90) | **8.0** (0.80) | **7.5** (0.75) |
| **WEIGHTED TOTAL (Out of 10.0)** | **100%** | **8.865 ≈ 8.87 / 10.0** | **6.41 / 10.0** | **7.045 ≈ 7.05 / 10.0** |

---

## 7. Architectural Path Comparison: Custom PCB (Path A) vs. Dev-Board-First (Path B)

```mermaid
flowchart TD
    subgraph Path_A["Path A: Custom PCB Direct"]
        A1["Design 4-Layer KiCad PCB (Week 1)"] --> A2["Fab at JLCPCB / LionCircuits"]
        A2 --> A3["Assembly via PTC Hot Plate OR Local Rework"]
        A3 --> A4["Test Cellular, GNSS & Firmware"]
    end

    subgraph Path_B["Path B: Staged Prototype (Dev Board First)"]
        B1["Order SIM7080G HAT / Dev Board (~₹3,839)"] --> B2["Verify SIM, NB-IoT Network & Cloud"]
        B2 --> B3["Design Custom PCB with De-risked Circuitry"]
        B3 --> B4["Fab & Final Assembly"]
    end

    style Path_A fill:#F3E5F5,stroke:#7B1FA2,stroke-width:2px
    style Path_B fill:#E8EAF6,stroke:#283593,stroke-width:2px
```

### Path A: Custom PCB with Planned Assembly Accommodation
- **Description:** Move directly into KiCad 4-layer PCB design in Week 1. Address the assembly constraint by allocating ~$12 USD (~₹1,000 INR) for a mini PTC hot plate + solder paste, or leveraging a local electronics repair shop for the SiP.
- **Advantages:**
  - Keeps 100% of the $100 budget focused on the final product.
  - Achieves the miniature 40×30 mm target form factor immediately.
  - Aligns directly with Hack Club Half Life Week 1 milestones.
- **Risks:**
  - High blast radius if local cellular coverage fails or the custom PCB has schematic/layout defects.
- **Decision Gates:**
  - **Gate A1:** Can a ₹450 INR PTC hot plate or local repair shop assistance be confirmed?
  - **Gate A2:** Can the M2M SIM card be verified before submitting the PCB to fabrication?

### Path B: Development-Board-First Validation Followed by Custom PCB
- **Description:** Procure an existing development board (e.g., Waveshare SIM7080G HAT @ ₹3,839 INR / ~$46 USD) to confirm Indian NB-IoT connectivity, SIM activation, and antenna performance on a known-working platform before laying out custom silicon.
- **Advantages:**
  - De-risks RF, carrier registration, and AT-command logic with zero PCB hardware risk.
- **Risks & Budget Squeeze:**
  - **Budget Barrier:** Spending ₹3,839 ($46.00) on a development board leaves only **$54.00 USD (~₹4,510 INR)** for the subsequent custom PCB fabrication, shipping, components, and battery.
  - **nRF9151 Incompatibility:** An official nRF9151-DK costs **₹9,450 to ₹11,750 INR ($115 to $130 USD)**, which completely exceeds the entire $100 project budget on day one.
  - **Schedule Compression:** Waiting for dev board delivery and testing compresses the timeline for designing and fabricating the custom PCB required by Half Life.
- **Decision Gates:**
  - **Gate B1:** Does the Half Life program permit using project funds for a development board in Phase 1 if the remaining budget is tight for Phase 2?

---

## 8. Remaining Risks & Evidence Needed to Close the Decision

The cellular/GNSS platform selection remains **OPEN**. To close Topic 1 in `docs/decisions/DECISION_LOG.md`, the following evidence must be provided:

1. **Tooling Confirmation:**
   - Will the project strictly enforce "soldering iron only", or will a ₹450 INR (~$5.40 USD) PTC hot plate or local repair technician be adopted?
   - *If strictly soldering iron only:* nRF9151 is eliminated; SIM7080G with bottom via accommodation becomes the primary candidate.
   - *If hot plate / local rework is accepted:* nRF9151 remains the dominant architectural candidate due to software velocity, footprint, and sleep current.
2. **SIM Provider & APN Verification:**
   - Confirm the exact provider of the IoT SIM card and whether it supports 3GPP NB-IoT APN attachment in India.
3. **Local Carrier Band Confirmation:**
   - Confirm whether local towers have active Band 3, Band 5, or Band 8 NB-IoT service.
4. **Half Life Milestone Alignment:**
   - Confirm whether Week 1 submission requires an initial custom PCB schematic commit or permits an initial validation breadboard log.

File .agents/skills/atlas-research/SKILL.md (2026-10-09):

---
name: atlas-research
description: >-
  Investigate hardware components and technical candidates for AtlasTag using evidence from
  manufacturer datasheets, hardware integration manuals, and authorized distributor listings.
  Use when evaluating new ICs, antennas, sensors, or power management options.
---

# AtlasTag Hardware Candidate Research Procedure

Use this skill when investigating new components or evaluating technical options for the AtlasTag project.

---

## Operating Guidelines

- **Primary Sources Only:** Always base technical evaluations on official manufacturer datasheets, reference schematics, errata, and authorized distributor data sheets.
- **No Inventions:** Never fabricate part specifications, pinouts, price quotes, or availability.
- **Explicit Assumptions:** Clearly distinguish verified specifications from engineering estimates or vendor marketing claims.

---

## Step-by-Step Procedure

### 1. Define Requirements & Constraints
- Identify the exact functional role (e.g., Cellular Modem, GNSS Engine, Accelerometer, PMIC, Storage, Antenna).
- Identify system constraints:
  - Supply voltage ranges (e.g., Li-Po 3.0V–4.2V, 3.3V, 1.8V).
  - Quiescent current budget (< 10 µA system sleep target).
  - Physical package constraints (LGA, QFN, SOIC, passive geometry).
  - Host digital interfaces (I2C, SPI, UART, GPIO interrupts).

### 2. Retrieve Primary Documentation
- Locate the official datasheet, hardware integration manual, and reference layout guide from the manufacturer (Nordic Semiconductor, STMicroelectronics, Quectel, Winbond, etc.).
- Record the exact document revision, publication date, and source URL.

### 3. Extract Technical Specifications
Extract and verify:
- **Electrical Ratings:** Input voltage range, absolute maximum ratings, logic level compatibility.
- **Power Consumption:** Active current, sleep/PSM current, peak transmit current bursts.
- **Interfaces & Pinout:** Required digital buses, decoupling requirements, external passives, pull-up values.
- **RF Requirements:** Matched 50Ω transmission line requirements, external LNA needs, antenna keepout areas.
- **Thermal & Environmental:** Operating temperature range, moisture sensitivity level (MSL).

### 4. Verify Sourcing & Regional Compatibility
- For cellular/RF devices, verify band support for target deployment regions (LTE-M bands: B2, B4, B12, B28; NB-IoT bands).
- Verify stock availability and lead times on authorized distributors (Mouser India, DigiKey India, Robu.in, LCSC).
- Record unit pricing at 1-qty and 10-qty breaks in both USD ($) and INR (₹).

### 5. Document Findings
- Update `docs/research/RESEARCH_INDEX.md` with:
  - Component name, manufacturer, and exact MPN.
  - Package type and dimensions.
  - Power profiles (active and standby).
  - Key pros, cons, and implementation risks.
  - Primary source citations and documentation URLs.

### 6. Synthesize Summary & Identify Gaps
- Provide a concise summary to the user:
  - **Verified Facts:** What the datasheet conclusively proves.
  - **Uncertainties / Risks:** Errata, difficult assembly footprints (e.g., fine-pitch BGA/LGA), or missing RF data.
  - **Recommended Next Investigation:** Next testing or decision step needed.

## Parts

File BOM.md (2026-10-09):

# ATLASTAG – bill of materials

<!-- Generated by Half Life from project cmuutecum0aay01sm51zcm57a. Edits here are overwritten on the next sync. -->
<!-- Generated: 2026-10-09T13:35:07.630Z -->

> [!NOTE]
> This parts list is mirrored from [Half Life](https://halflife.hackclub.com). Editing it here will not change the platform's copy, and the next sync overwrites this file.

| Week | Tier | Parts funding |
| --- | --- | --- |
| Week 1 | Tier 3 | $100.00 |

| Part | What it's for | Qty | Unit | Total | Vendor |
| --- | --- | --- | --- | --- | --- |
| Linear CC/CV Li-Po Charger IC | — | 1 | $0.50 | $0.50 | Microchip |
| Ultra-Low-Dropout 3.3V 600mA LDO | — | 1 | $0.33 | $0.33 | Diodes Inc |
| 32Mb High-Speed SPI NOR Flash | — | 1 | $1.20 | $1.20 | Winbond |
| 6-Pin Power-Only USB-C Receptacle | — | 1 | $0.45 | $0.45 | Korean HRO |
| 2-Pin 2.0mm Li-Po Battery Header | — | 1 | $0.25 | $0.25 | JST |
| 5-Pin 2.54mm I2C Sensor Header | — | 1 | $0.15 | $0.15 | Generic |
| 16-Pin 2.54mm Modular Interface | — | 1 | $0.30 | $0.30 | Generic |
| Push-Pull Nano-SIM (4FF) Socket | — | 1 | $1.62 | $1.62 | Molex |
| 100uF 10V Low-ESR Polymer/Tantalum | — | 1 | $0.85 | $0.85 | Panasonic |
| Red 0603 SMD LED | — | 1 | $0.10 | $0.10 | Everlight |
| Green 0603 SMD LED | — | 1 | $0.10 | $0.10 | Everlight |
| Momentary Tactile Switch | — | 1 | $0.35 | $0.35 | C&K |
| 3.7V 500mAh 1S Li-Po with PCM | — | 1 | $3.00 | $3.00 | WLY / Generic |
| 0603 Resistors & Capacitors (Kit) | — | 1 | $2.50 | $2.50 | Yageo / Murata |
| **Parts subtotal** | — | — | — | **$11.70** | — |
| **Tax & shipping** | — | — | — | **$0.00** | — |
| **Total** | — | — | — | **$11.70** | — |

$88.30 left of the tier's funding.

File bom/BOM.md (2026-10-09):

# AtlasTag — Detailed Bill of Materials (BOM)

> **Project:** AtlasTag (Hack Club Half Life)  
> **Target Tier:** Week 1 — Tier 3  
> **Exchange Rate:** **1.00 USD = ₹96.70 INR**  
> **Parts Funding Limit:** **$100.00 USD** (**₹9,670.00 INR**)  
> **Baseboard Prototype BOM (Week 1 Physical Build):** **$11.70 USD** / **₹1,131.41 INR**  
> **Estimated Full System BOM (Envisioned Complete Tracker):** **$44.25 USD** / **₹4,278.98 INR**  
> **Total Funding Headroom (Under Tier 3 Limit):** **$55.75 USD** / **₹5,391.02 INR**

---

## 1. BOM Reconciliation: Prototype Baseboard vs. Full System

| Scope | USD ($) | INR (₹ @ 96.70) | Description & Status |
| :--- | :--- | :--- | :--- |
| **Modular Baseboard Prototype (Week 1)** | **$11.70** | **₹1,131.41** | **Active Design (Reflected in `bom.csv` and KiCad baseboard design).** Solderable power management (MCP73831, AP2112K-3.3), offline SPI Flash (W25Q32), Nano-SIM socket, motion port, and mezzanine header. |
| **Envisioned Full Tracking System** | **$44.25** | **₹4,278.98** | **System Budget Projection.** Includes candidate cellular/GNSS platform ($25.40), PMIC ($3.45), accelerometer ($2.02), antennas ($3.83), battery ($3.00), and baseboard passives. Proves feasibility under the $100 budget cap. |

---

## 2. Modular Prototype Baseboard BOM (Active Week 1 Build)

*Directly matches `hardware/kicad/atlastag.kicad_sch`, `hardware/kicad/atlastag.kicad_pcb`, and `bom.csv`.*

| RefDes | Subsystem | Description | Manufacturer | Part Number (MPN) | Package / Footprint | Vendor Source | Unit Price (USD $) | Unit Price (INR ₹) | Qty | Total (USD $) | Total (INR ₹) |
| :--- | :--- | :--- | :--- | :--- | :--- | :--- | :--- | :--- | :--- | :--- | :--- |
| **U1** | Battery Charger | Linear CC/CV Li-Po Charger IC (212mA) | Microchip | **MCP73831T-2ACI/OT** | SOT-23-5 | Mouser | $0.50 | ₹48.35 | 1 | $0.50 | ₹48.35 |
| **U2** | Voltage Regulator | Ultra-Low-Dropout 3.3V 600mA LDO | Diodes Inc | **AP2112K-3.3TRG1** | SOT-23-5 | Mouser | $0.33 | ₹31.91 | 1 | $0.33 | ₹31.91 |
| **U3** | Telemetry Memory | 32Mb (4MB) High-Speed SPI NOR Flash | Winbond | **W25Q32JVSSIQ** | SOIC-8 (208 mil) | Evelta / Mouser | $1.20 | ₹116.04 | 1 | $1.20 | ₹116.04 |
| **J1** | 5V Power Port | 16-Pin USB-C Receptacle (5V Power) | Korean HRO / GCT | **TYPE-C-31-M-12** | Mid-Mount SMT | LCSC / Mouser | $0.45 | ₹43.52 | 1 | $0.45 | ₹43.52 |
| **J2** | Battery Port | 2-Pin 2.0mm Li-Po Header | JST | **S2B-PH-K-S** | Through-Hole 2.0mm | Robu.in / Mouser | $0.25 | ₹24.18 | 1 | $0.25 | ₹24.18 |
| **J3** | Motion Port | 5-Pin 2.54mm I2C Sensor Header | Generic | **PinHeader_1x05** | Through-Hole 2.54mm | Robu.in | $0.15 | ₹14.51 | 1 | $0.15 | ₹14.51 |
| **J4** | Modem Mezzanine | 16-Pin 2.54mm Mezzanine Interface | Generic | **PinHeader_2x08** | Through-Hole 2.54mm | Robu.in | $0.30 | ₹29.01 | 1 | $0.30 | ₹29.01 |
| **J5** | SIM Socket | Push-Pull Nano-SIM (4FF) Socket | GCT / Molex | **SIM8060-6-0-14-00** | SMT Perimeter | Mouser / LCSC | $1.62 | ₹156.65 | 1 | $1.62 | ₹156.65 |
| **C3** | Burst Bulk Cap | 100µF 10V Low-ESR Polymer/Tantalum | Panasonic / Kemet | **CP_EIA-3528-21** | EIA 3528-21 SMD | Mouser | $0.85 | ₹82.20 | 1 | $0.85 | ₹82.20 |
| **D1** | Charge LED | Red 0603 SMD LED | Everlight | **19-217/R6C-AL1M2VY/3T** | 0603 Metric | Mouser | $0.10 | ₹9.67 | 1 | $0.10 | ₹9.67 |
| **D2** | Power LED | Green 0603 SMD LED | Everlight | **19-217/GHC-YR1S2/3T** | 0603 Metric | Mouser | $0.10 | ₹9.67 | 1 | $0.10 | ₹9.67 |
| **SW1** | User Button | Tactile Push Switch | C&K | **PTS645Sx43SMTR92** | SMT Gull-Wing | Mouser | $0.35 | ₹33.85 | 1 | $0.35 | ₹33.85 |
| **BAT1**| Battery | 3.7V 500mAh 1S Li-Po Cell (with PCM) | WLY / Robu.in | **WLY902030** | Prismatic w/ Leads | Robu.in | $3.00 | ₹290.10 | 1 | $3.00 | ₹290.10 |
| **PASS**| Passives Kit | 0603 Resistors (R1–R15) & Caps (C1–C8) | Yageo / Murata | **Generic 0603 Kit** | 0603 Metric | Robu / Mouser | $2.50 | ₹241.75 | 1 | $2.50 | ₹241.75 |
| **TOTAL**| | **Modular Baseboard Prototype Subtotal** | | | | | | | | **$11.70** | **₹1,131.41** |

---

## 3. Envisioned Full System BOM (Candidate Monolithic SiP Concept)

*Maintained to verify that the complete standalone tracker fits under the $100 Half Life budget cap.*

| RefDes | Subsystem | Description | Manufacturer | Part Number (MPN) | Footprint / Package | Vendor Source | Unit Price (USD $) | Unit Price (INR ₹) | Qty | Total (USD $) | Total (INR ₹) |
| :--- | :--- | :--- | :--- | :--- | :--- | :--- | :--- | :--- | :--- | :--- | :--- |
| **U1** | Cellular + GNSS SoC | LTE-M / NB-IoT SiP with Cortex-M33 & GNSS | Nordic Semi | **NRF9151-LACA-R** | LGA-114 (12.1×11.1mm) | Mouser India | $25.40 | ₹2,456.18 | 1 | $25.40 | ₹2,456.18 |
| **U2** | Power Management | Smart PMIC with CC/CV Li-Po Charger | Nordic Semi | **nPM1300-QEAA-R** | QFN-32 (5.0×5.0mm) | Mouser India | $3.45 | ₹333.62 | 1 | $3.45 | ₹333.62 |
| **U3** | Motion Sensor | Ultra-low-power 3-axis accelerometer | STMicro | **LIS2DW12TR** | LGA-12 (2.0×2.0mm) | Mouser India | $2.02 | ₹195.33 | 1 | $2.02 | ₹195.33 |
| **U4** | Telemetry Memory | 32Mb SPI NOR Flash Telemetry Queue | Winbond | **W25Q32JVSSIQ** | SOIC-8 (208 mil) | Mouser / Evelta | $1.20 | ₹116.04 | 1 | $1.20 | ₹116.04 |
| **ANT1**| Cellular Antenna | RUN mXTEND™ Wideband Virtual Antenna | Ignion | **NN02-224** | SMD (12.0×3.0mm) | DigiKey India | $1.35 | ₹130.55 | 1 | $1.35 | ₹130.55 |
| **ANT2**| GNSS Antenna | 1575.42 MHz Ceramic Patch Antenna | Abracon | **APAE1575R2540BBDB1-T** | SMD Patch (25×25×4mm) | DigiKey India | $2.48 | ₹239.82 | 1 | $2.48 | ₹239.82 |
| **J1** | Charge & USB Port | 16-Pin USB Type-C Receptacle | GCT | **USB4105-GF-A** | Surface Mount | Mouser India | $0.90 | ₹87.03 | 1 | $0.90 | ₹87.03 |
| **J2** | SIM Interface | Push-Pull Nano-SIM (4FF) Socket | Molex | **104224-0820** | SMT (12.1×11.5mm) | Mouser India | $1.62 | ₹156.65 | 1 | $1.62 | ₹156.65 |
| **BAT1**| Battery | 3.7V 500mAh 1S Li-Po Battery with PCM | Robu.in / WLY | **WLY902030** | Prismatic w/ Leads | Robu.in | $3.00 | ₹290.10 | 1 | $3.00 | ₹290.10 |
| **PASS**| Passive Kit | Decoupling caps, pull-ups, RF matching | Yageo / Murata | **Generic Passives Kit** | 0402 / 0603 | Robu / Mouser | $2.83 | ₹273.66 | 1 | $2.83 | ₹273.66 |
| **TOTAL**| | **Envisioned Full System Subtotal** | | | | | | | | **$44.25** | **₹4,278.98** |

---

## 4. Half Life Tier 3 Budget Analysis

| Parameter | Value in USD ($) | Value in INR (₹ @ 96.70) | Allocation Status |
| :--- | :--- | :--- | :--- |
| **Hack Club Half Life Tier 3 Parts Funding Cap** | **$100.00** | **₹9,670.00** | Maximum Allowed Funding |
| **AtlasTag Envisioned Core System BOM** | **$44.25** | **₹4,278.98** | Full Tracker Cost Projection |
| **Estimated Custom PCB Fab (5 pcs @ JLCPCB/LionCircuits)** | **$15.00** | **₹1,450.50** | Budgeted Manufacturing Reserve |
| **SMD Stencil & Solder Consumables** | **$8.00** | **₹773.60** | Budgeted Tooling Reserve |
| **Remaining Contingency Margin** | **$32.75** | **₹3,166.92** | Unallocated Buffer |
| **Total Projected Project Expenditure** | **$67.25** | **₹6,503.08** | **Comfortably within $100 Cap ($32.75 / ₹3,166.92 Headroom)** |

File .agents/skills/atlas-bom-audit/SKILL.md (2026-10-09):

---
name: atlas-bom-audit
description: >-
  Audit and verify the AtlasTag Bill of Materials (BOM), cross-checking part numbers, footprints,
  stock availability, distributor pricing in USD and INR, and budget compliance against Half Life limits.
  Use during component updates, price verifications, or pre-milestone reviews.
---

# AtlasTag Bill of Materials (BOM) Audit Procedure

Use this skill to inspect, audit, and validate component selections, pricing, and budget allocations in `bom/BOM.md` and root `BOM.md`.

---

## Operating Guidelines

- **Fact-Based Pricing:** Never claim a live price check unless actual distributor web tools were run. When estimating, explicitly label entries as "Estimates".
- **Half Life Mirror Preservation:** Never overwrite or corrupt the automated sync sections in root `BOM.md`. The detailed engineering BOM resides in `bom/BOM.md`.
- **Budget Tracking:** Track all items against the **$100.00 USD** (~₹8,350 INR) Half Life Tier 3 parts limit.

---

## Step-by-Step Procedure

### 1. Inspect Authoritative BOM
- Read `bom/BOM.md`.
- Verify each line item contains:
  - Reference Designator (`RefDes`).
  - Subsystem role.
  - Manufacturer Name.
  - Full Manufacturer Part Number (`MPN`).
  - Package / Footprint code.
  - Quantity per board (`Qty`).
  - Unit Price in Indian Rupees (`INR ₹`).
  - Unit Price in US Dollars (`USD $`).
  - Primary sourcing distributor link.

### 2. Verify Part Numbers & Footprints
- Cross-check that the MPN ordering code matches the intended footprint (e.g., tape-and-reel suffix `-R` vs. cut tape, temperature ratings, voltage suffix).
- Verify footprint geometry matches standard IPC libraries or manufacturer recommended landing patterns.

### 3. Verify Distributor Pricing & Availability
- Check authorized distributor listings (Mouser India, DigiKey India, Robu.in, Evelta):
  - Confirm part is marked "In Stock" or has acceptable lead times.
  - Record price at quantity = 1 (or relevant prototype quantity).
  - Record the date of retrieval and currency exchange rate used.
- Account for Indian procurement logistics:
  - Mouser India: 18% GST business invoice eligible; free shipping threshold (₹4,000 / ~$50).
  - DigiKey India: Free shipping threshold (₹7,000 / ~$85).
  - Domestic suppliers (Robu.in): Mandatory for Li-Po batteries to prevent IATA DG air cargo rejection.

### 4. Mathematical Audit & Classification
- Recalculate all line-item extended costs: $\text{Total} = \text{Qty} \times \text{Unit Price}$.
- Sum the core BOM subtotal in both USD and INR.
- Separate expenses into clear categories:
  - **Verified Component Costs:** Live quotes from authorized distributors.
  - **Estimated Passives / Hardware:** Labeled estimates (e.g., generic 0402 caps/resistors).
  - **Manufacturing Spares & Fab:** Prototype PCB fabrication (5 pcs), SMD stencils.
  - **Contingency Reserve:** Unallocated balance.

### 5. Generate Audit Report
Provide a structured audit report to the user:
- Current Core BOM Total vs. $100.00 funding limit.
- Remaining budget headroom.
- Component risks (single-source items, low stock, lead time warnings).
- Out-of-sync discrepancies between `bom/BOM.md` and root `BOM.md`.

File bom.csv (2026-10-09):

Designator | Subsystem | Description | Manufacturer | Part Number | Package | Vendor | Unit Price (USD) | Unit Price (INR @ 96.70) | Quantity | Total (USD) | Total (INR)
U1 | Battery Charger | Linear CC/CV Li-Po Charger IC | Microchip | MCP73831T-2ACI/OT | SOT-23-5 | Mouser | 0.50 | 48.35 | 1 | 0.50 | 48.35
U2 | Voltage Regulator | Ultra-Low-Dropout 3.3V 600mA LDO | Diodes Inc | AP2112K-3.3TRG1 | SOT-23-5 | Mouser | 0.33 | 31.91 | 1 | 0.33 | 31.91
U3 | Telemetry Flash | 32Mb High-Speed SPI NOR Flash | Winbond | W25Q32JVSSIQ | SOIC-8 208mil | Mouser / Evelta | 1.20 | 116.04 | 1 | 1.20 | 116.04
J1 | 5V Power Port | 6-Pin Power-Only USB-C Receptacle | Korean HRO | TYPE-C-31-M-12 | SMT Mid-Mount | LCSC / Mouser | 0.45 | 43.52 | 1 | 0.45 | 43.52
J2 | Battery Port | 2-Pin 2.0mm Li-Po Battery Header | JST | S2B-PH-K-S | Through-Hole 2.0mm | Robu.in / Mouser | 0.25 | 24.18 | 1 | 0.25 | 24.18
J3 | Motion Sensor Port | 5-Pin 2.54mm I2C Sensor Header | Generic | PinHeader_1x05 | Through-Hole 2.54mm | Robu.in | 0.15 | 14.51 | 1 | 0.15 | 14.51
J4 | Modem Mezzanine | 16-Pin 2.54mm Modular Interface | Generic | PinHeader_2x08 | Through-Hole 2.54mm | Robu.in | 0.30 | 29.01 | 1 | 0.30 | 29.01
J5 | SIM Socket | Push-Pull Nano-SIM (4FF) Socket | Molex | 104224-0820 | SMT Perimeter | Mouser | 1.62 | 156.65 | 1 | 1.62 | 156.65
C3 | Burst Bulk Cap | 100uF 10V Low-ESR Polymer/Tantalum | Panasonic | CP_EIA-3528-21 | EIA 3528-21 SMD | Mouser | 0.85 | 82.20 | 1 | 0.85 | 82.20
D1 | Charge LED | Red 0603 SMD LED | Everlight | 19-217/R6C-AL1M2VY/3T | 0603 Metric | Mouser | 0.10 | 9.67 | 1 | 0.10 | 9.67
D2 | Power LED | Green 0603 SMD LED | Everlight | 19-217/GHC-YR1S2/3T | 0603 Metric | Mouser | 0.10 | 9.67 | 1 | 0.10 | 9.67
SW1 | User Button | Momentary Tactile Switch | C&K | PTS645Sx43SMTR92 | SMT Gull-Wing | Mouser | 0.35 | 33.85 | 1 | 0.35 | 33.85
BAT1 | Battery | 3.7V 500mAh 1S Li-Po with PCM | WLY / Generic | WLY902030 | Prismatic with leads | Robu.in | 3.00 | 290.10 | 1 | 3.00 | 290.10
PASS | Passives Kit | 0603 Resistors & Capacitors (Kit) | Yageo / Murata | Generic 0603 Kit | 0603 Metric | Robu / Mouser | 2.50 | 241.75 | 1 | 2.50 | 241.75
TOTAL | Baseboard BOM | Total Component Parts Cost |  |  |  |  |  |  |  |  | 11.70 | 1131.41

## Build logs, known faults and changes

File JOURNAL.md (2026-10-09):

# ATLASTAG – devlog

<!-- Generated by Half Life from project cmuutecum0aay01sm51zcm57a. Edits here are overwritten on the next sync. -->
<!-- Generated: 2026-10-09T12:50:27.799Z -->

> [!NOTE]
> This devlog is mirrored from [Half Life](https://halflife.hackclub.com). Editing it here will not change the platform's copy, and the next sync overwrites this file.

> A slim, battery-powered, globally connected asset-tracking device that can determine its location using GNSS and cellular positioning, transmit telemetry over cellular IoT networks, and provide location, movement, battery, and device-status information through a companion phone application.

| Week | Tier | Hours logged | Entries |
| --- | --- | --- | --- |
| Week 1 | Tier 3 | 5.14h | 3 |

## Contents

1. [2026-10-08 – ![AtlasTag Global Tracking Poster](https://halflife.hackclub-assets.com/hackclub-half-life/sessions/w890EgVDHUHryLXezmpxYEln7rcgrK0C/82f13571bddfde49df86fc792f5c40ac02910586da929b369e8ccf5a2bf2f738.pn](#2026-10-08-atlastag-global-tracking-posterhttpshalflifehackc)
2. [2026-10-09 – Work session](#2026-10-09-work-session)
3. [2026-10-09 – Work session](#2026-10-09-work-session)

## Design

### 2026-10-08 – ![AtlasTag Global Tracking Poster](https://halflife.hackclub-assets.com/hackclub-half-life/sessions/w890EgVDHUHryLXezmpxYEln7rcgrK0C/82f13571bddfde49df86fc792f5c40ac02910586da929b369e8ccf5a2bf2f738.pn

**2h**

AtlasTag Global Tracking Poster

- Started building the foundation for AtlasTag.
- Set up the GitHub repository and development workflow.
- Documented the initial requirements and system architecture.
- Researched cellular + GNSS modules, motion sensors, power management, storage, SIMs, and antennas.
- Started building the BOM with real Indian component pricing.
- Compared different approaches for making AtlasTag compact, battery-powered, and globally connected.
- Identified the cellular + GNSS platform as the biggest decision before moving into PCB design.
What I learned:
- Hardware design starts with making the right architectural decisions.
- Choosing the wrong cellular/GNSS platform can affect the PCB, power, firmware, antenna, size, and cost.
- I need to validate the core hardware before jumping into PCB design.
Next:
- Deep-dive into the cellular + GNSS options.
- Finalize the core hardware platform.
- Start moving from research → actual PCB design.

Github Repo: https://github.com/riteshbonthalakoti



### 2026-10-09 – Work session

**1.12h**

[Timelapse](https://lookout.hackclub.com/api/media/d79b8ef9-d776-4d00-88ce-cb59a364236e/video.mp4)

### 2026-10-09 – Work session

**2.02h**

[Timelapse](https://lookout.hackclub.com/api/media/d3748e9d-d1e8-4a68-9a71-cbe8432bfbbf/video.mp4)

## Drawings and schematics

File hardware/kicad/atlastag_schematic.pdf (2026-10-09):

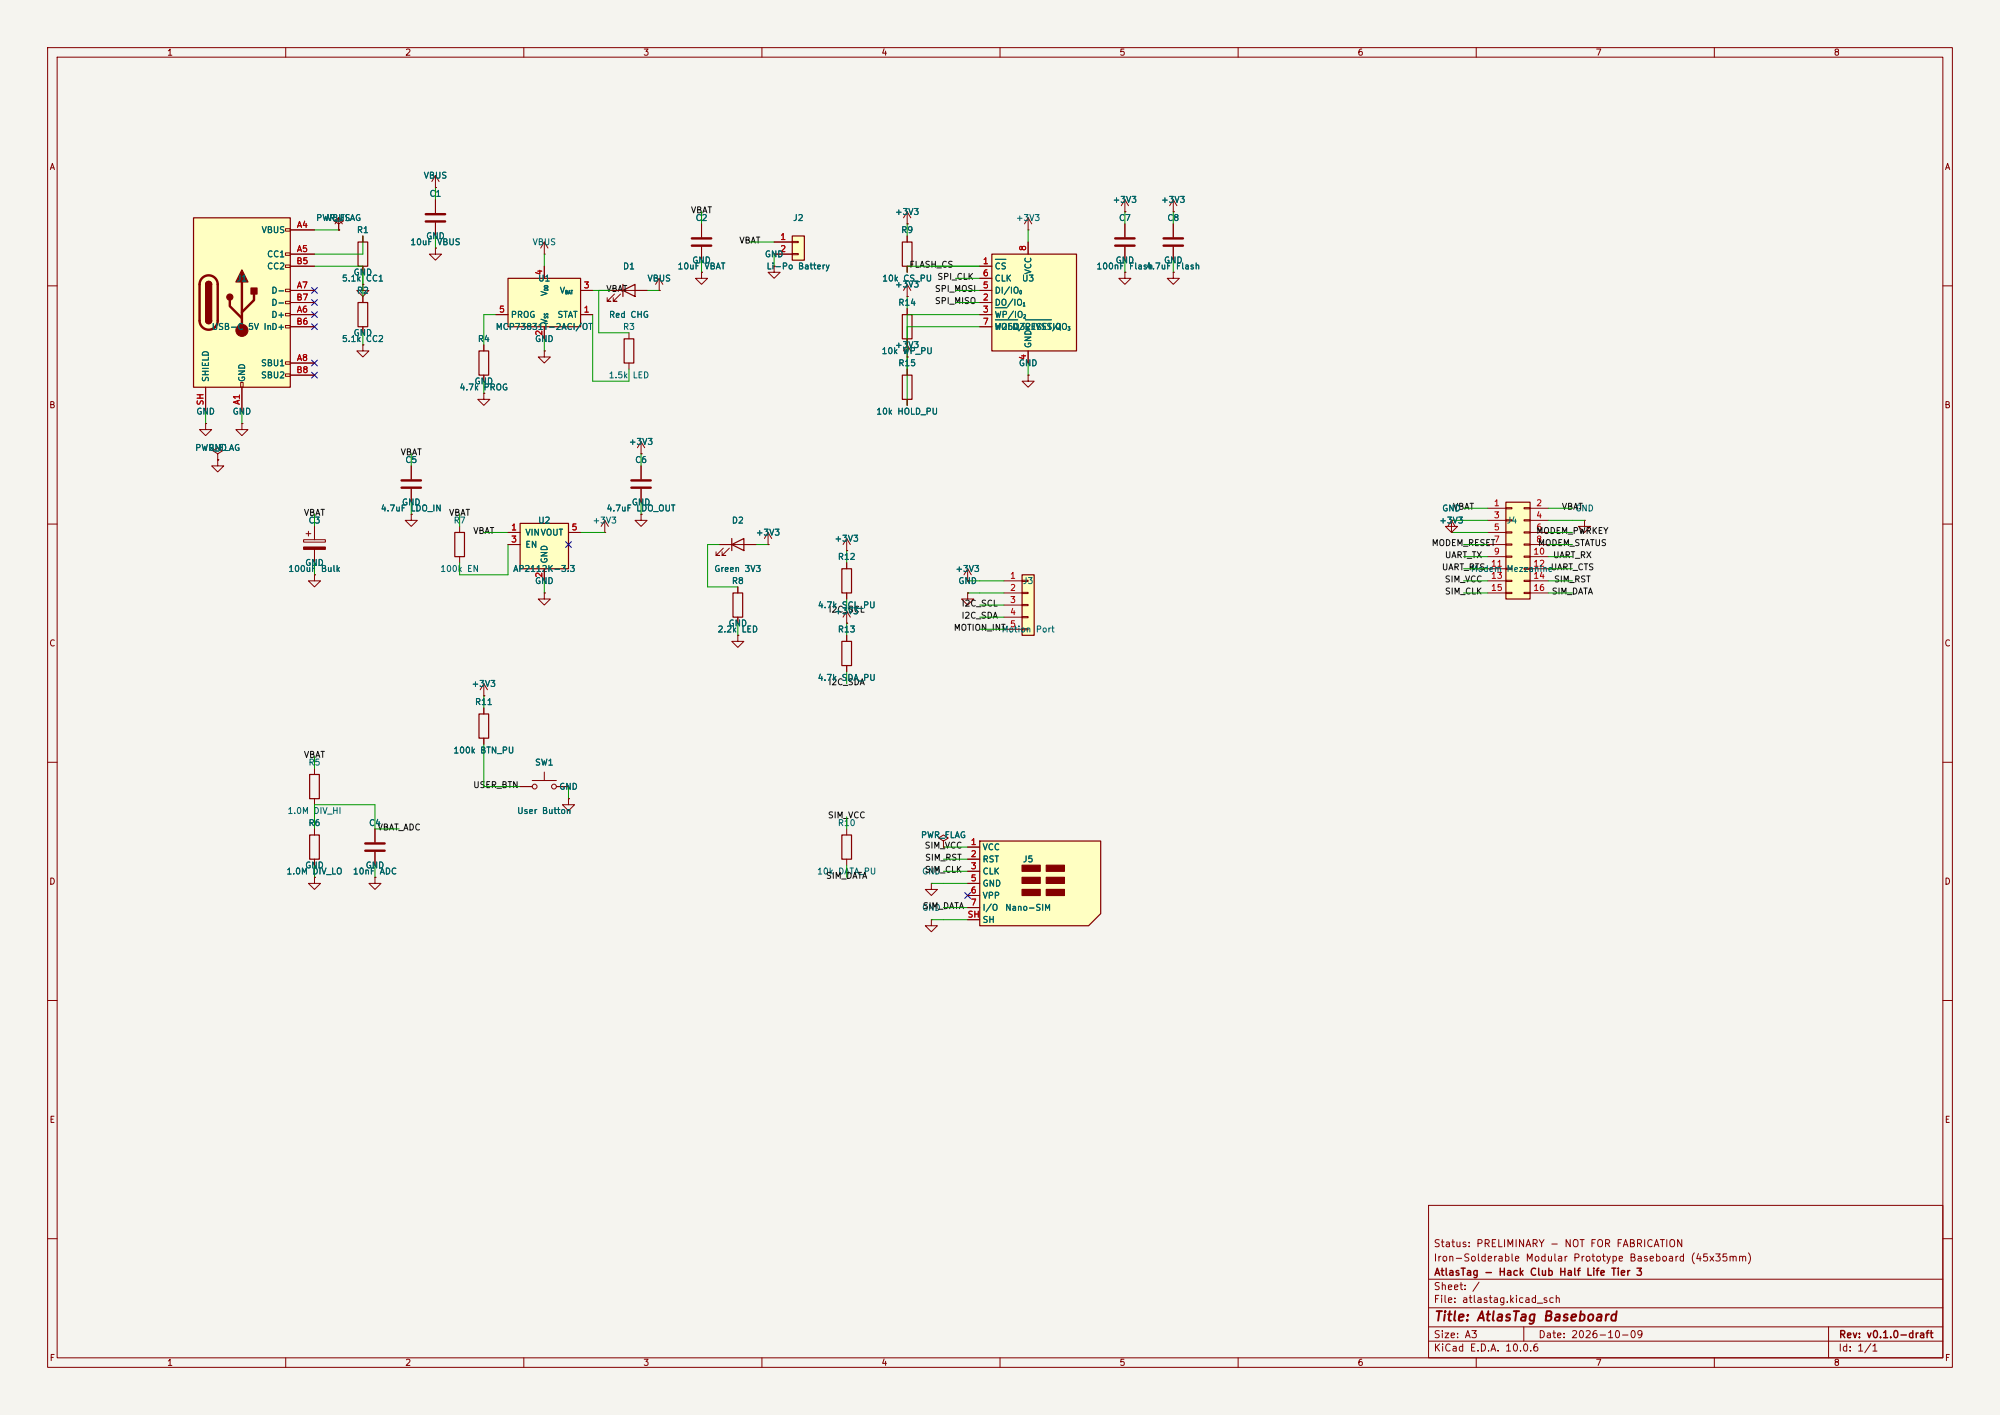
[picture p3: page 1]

VDD 4 PROG 5 U1 MCP73831T-2ACI/OT VBUS GND

4 DI/IO0 5 CLK 6 HOLD/RESET/IO3 7 VCC

VCC 1 RST 2 CLK 3 GND 5

Status: PRELIMINARY - NOT FOR FABRICATION
Iron-Solderable Modular Prototype Baseboard (45x35mm)
AtlasTag - Hack Club Half Life Tier 3
Sheet: /
File: atlastag.kicad_sch
Title: AtlasTag Baseboard

Size: A3 | Rev: v0.1.0-draft | F Date: 2026-10-09
KiCad E.D.A. 10.0.6 | Id: 1/1

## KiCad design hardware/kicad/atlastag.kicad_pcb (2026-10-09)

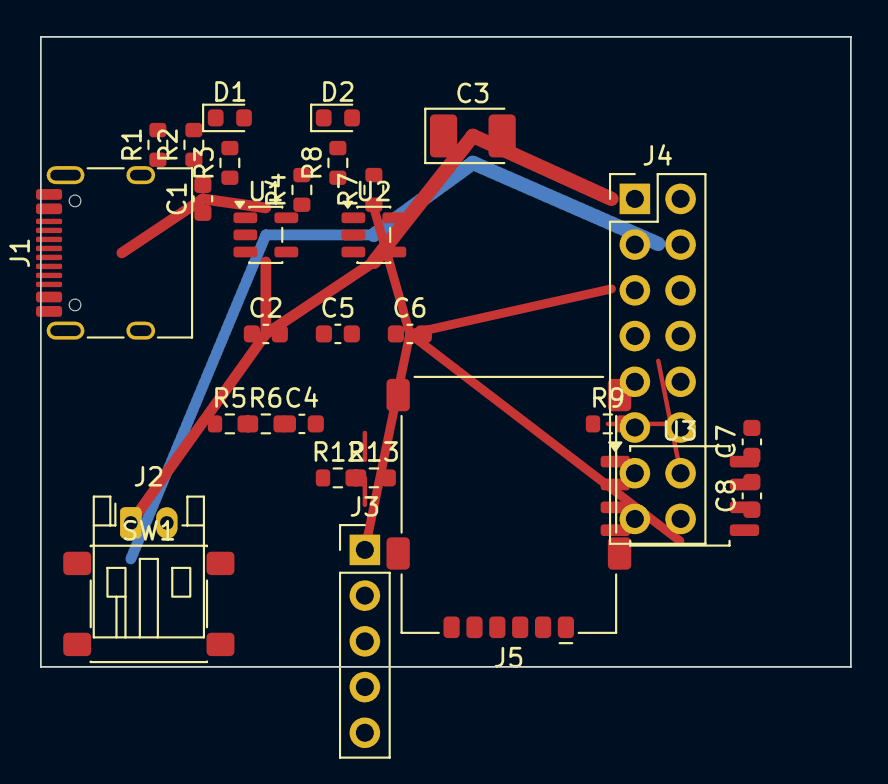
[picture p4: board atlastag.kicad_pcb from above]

Board: 4 copper layers, 45.0 x 35.0 mm, 30 parts (0 on the bottom side), 4 nets.

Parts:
C1: 10uF VBUS; C_0603_1608Metric
C2: 10uF VBAT; C_0603_1608Metric
C3: 100uF Bulk; CP_EIA-3528-21_Kemet-B_HandSolder
C4: 10nF ADC; C_0603_1608Metric
C5: 4.7uF LDO_IN; C_0603_1608Metric
C6: 4.7uF LDO_OUT; C_0603_1608Metric
C7: 100nF Flash; C_0603_1608Metric
C8: 4.7uF Flash; C_0603_1608Metric
D1: Red CHG; LED_0603_1608Metric
D2: Green 3V3; LED_0603_1608Metric
J1: USB-C 5V In; USB_C_Receptacle_HRO_TYPE-C-31-M-12
J2: Li-Po Battery; JST_PH_S2B-PH-K_1x02_P2.00mm_Horizontal
J3: Motion Port; PinHeader_1x05_P2.54mm_Vertical
J4: Modem Mezzanine; PinHeader_2x08_P2.54mm_Vertical
J5: Nano-SIM; nanoSIM_GCT_SIM8060-6-0-14-00
R1: 5.1k CC1; R_0603_1608Metric
R2: 5.1k CC2; R_0603_1608Metric
R3: 1.5k LED; R_0603_1608Metric
R4: 4.7k PROG; R_0603_1608Metric
R5: 1.0M DIV_HI; R_0603_1608Metric
R6: 1.0M DIV_LO; R_0603_1608Metric
R7: 100k LDO_EN; R_0603_1608Metric
R8: 2.2k LED; R_0603_1608Metric
R9: 10k CS_PU; R_0603_1608Metric
R12: 4.7k SCL_PU; R_0603_1608Metric
R13: 4.7k SDA_PU; R_0603_1608Metric
SW1: User Button; SW_SPST_PTS645Sx43SMTR92
U1: MCP73831T; SOT-23-5
U2: AP2112K-3.3; SOT-23-5
U3: W25Q32JV; SOIC-8_5.3x5.3mm_P1.27mm

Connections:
+3V3: C6.1, C7.1, C8.1, J3.1, J4.5, U2.5, U3.3, U3.7, U3.8
GND: C1.2, C2.2, C3.2, C5.2, C6.2, C7.2, C8.2, J2.2, J3.2, J4.3, J4.4, U1.2, U1.5, U2.2, U3.4
VBAT: C2.1, C3.1, C5.1, J2.1, J4.1, J4.2, U1.3, U2.1, U2.3
VBUS: C1.1, U1.4

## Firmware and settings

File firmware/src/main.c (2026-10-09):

/**
 * @file main.c
 * @brief AtlasTag Firmware — Architectural Conceptual Stub (Week 1 Checkpoint)
 * @project Hack Club Half Life (Tier 3)
 * @status STUB / ARCHITECTURAL MOCKUP — NOT PRODUCTION DRIVERS
 * @details This file provides an architectural reference model for state machine
 *          transitions and battery voltage threshold calculations. It uses mock
 *          data (hardcoded ADC sample values) and standard C library output.
 *          Target MCU hardware drivers (I2C for motion, SPI for NOR Flash,
 *          ADC HAL for battery sensing, UART for modem AT commands) will be
 *          implemented once the primary Cellular/GNSS platform and host MCU
 *          architecture are finalized.
 */

#include <stdint.h>
#include <stdbool.h>
#include <stdio.h>

/* Hardware Configuration Constants */
#define VBAT_DIVIDER_RATIO      2.0f      /* 1M / 1M resistive divider */
#define ADC_VREF_MV             3300      /* 3.3V System ADC reference */
#define BATTERY_MIN_SAFE_MV     3300      /* Cutoff threshold to prevent brownouts */
#define BATTERY_FULL_MV         4200      /* 1S Li-Po fully charged */

/* Operational State Definitions */
typedef enum {
    STATE_DEEP_SLEEP = 0,
    STATE_WAKE_MOTION,
    STATE_SAMPLE_BATTERY,
    STATE_QUEUE_TELEMETRY,
    STATE_MODEM_TX_BURST,
    STATE_POWER_ERROR
} system_state_t;

/* Telemetry Record Structure (stored in SPI Flash queue) */
typedef struct {
    uint32_t timestamp;
    uint16_t vbat_mv;
    int16_t  accel_x;
    int16_t  accel_y;
    int16_t  accel_z;
    uint8_t  status_flags;
} __attribute__((packed)) telemetry_record_t;

/* Global System State */
static system_state_t g_system_state = STATE_DEEP_SLEEP;

/**
 * @brief Convert raw ADC counts to battery millivolts
 */
uint16_t atlastag_read_battery_mv(uint16_t raw_adc, uint16_t adc_resolution) {
    if (adc_resolution == 0) return 0;
    float adc_voltage = ((float)raw_adc / (float)adc_resolution) * (float)ADC_VREF_MV;
    return (uint16_t)(adc_voltage * VBAT_DIVIDER_RATIO);
}

/**
 * @brief Verify battery voltage is sufficient for cellular RF burst
 */
bool atlastag_is_battery_safe(uint16_t vbat_mv) {
    return (vbat_mv >= BATTERY_MIN_SAFE_MV);
}

/**
 * @brief Main execution entry point
 */
int main(void) {
    printf("[AtlasTag] Booting Modular Prototype Baseboard Firmware\n");
    printf("[AtlasTag] Hardware Version: v0.1.0-draft (Week 1 Checkpoint)\n");
    
    /* Initialize peripherals: I2C (Motion), SPI (NOR Flash), UART (Modem), ADC */
    g_system_state = STATE_SAMPLE_BATTERY;
    
    /* NOTE: Simulated ADC reading (2600 counts on 12-bit ADC / 4095 max, equivalent to ~4.18V).
     * Hardware ADC driver integration is pending target host MCU selection. */
    uint16_t current_vbat_mv = atlastag_read_battery_mv(2600, 4095);
    printf("[AtlasTag] Battery Voltage (Simulated): %u mV\n", current_vbat_mv);
    
    if (!atlastag_is_battery_safe(current_vbat_mv)) {
        printf("[AtlasTag] WARNING: Low battery. Cellular Tx inhibited to prevent brownout.\n");
        g_system_state = STATE_POWER_ERROR;
        return -1;
    }
    
    printf("[AtlasTag] Entering motion-triggered sleep mode.\n");
    g_system_state = STATE_DEEP_SLEEP;
    
    return 0;
}

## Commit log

2026-10-05 chore: initialize AtlasTag project
    [BOM-DRAFT.csv]
2026-10-06 docs: add simplified visual flow architecture diagram and workflow
2026-10-08 docs(bom): add real Indian (INR) and USD distributor pricing and sourcing breakdown
    [BOM-DRAFT.csv]
2026-10-08 chore(bom): remove BOM-DRAFT.csv
    [BOM-DRAFT.csv]
2026-10-09 feat(hardware): implement modular baseboard PCB design, firmware starter, and Week 1 deliverables
    [atlastag-B_Courtyard.gbr, atlastag-B_Cu.gbl, atlastag-B_Fab.gbr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]
2026-10-09 fix(hardware): audit PR #4, implement complete baseboard schematic, and reconcile status claims
    - Capture complete KiCad 10 baseboard schematic with real symbols, nets, power ports, and verified footprints
    - Decouple Cellular/GNSS modem via 16-pin modular mezzanine interface to keep platform decision open
    - Add Microchip MCP73831 212 mA linear charger, AP2112K-3.3 LDO, Winbond W25Q32 SOIC-8 flash, Nano-SIM socket, and motion breakout header
    - Run schematic ERC and commit authoritative report (hardware/kicad/atlastag_erc.rpt)
    - Clarify firmware/src/main.c as an architectural stub using simulated ADC values
    - Reconcile BOMs at verified INR rate (₹96.70/USD) distinguishing .70 baseboard build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
    [atlastag.kicad_sch, bom.csv]
